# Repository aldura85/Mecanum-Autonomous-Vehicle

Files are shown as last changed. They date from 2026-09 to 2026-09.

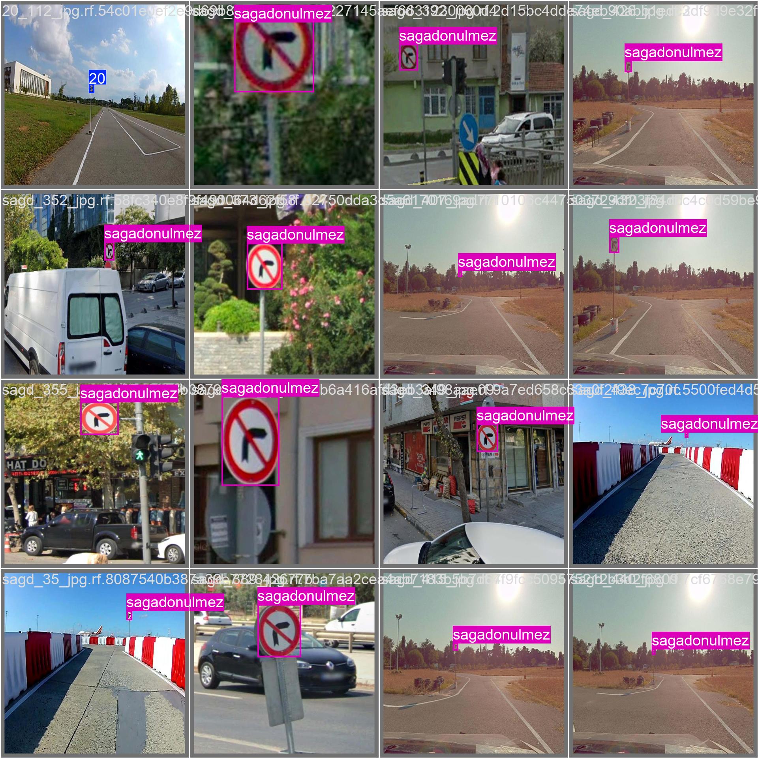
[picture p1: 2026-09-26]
project_codes/python_pc_folder/Yolo_training_reslut/val_batch0_labels.jpg

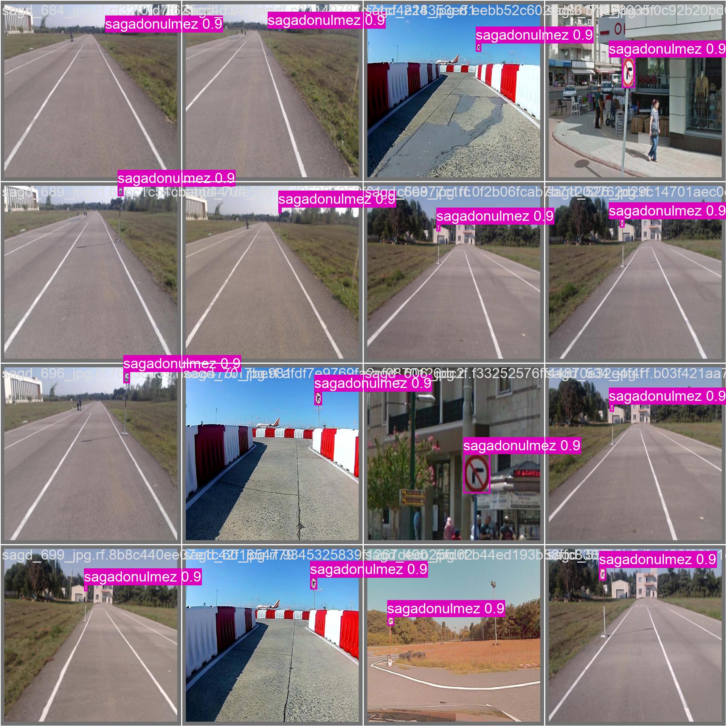
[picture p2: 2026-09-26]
project_codes/python_pc_folder/Yolo_training_reslut/val_batch2_pred.jpg

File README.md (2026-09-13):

# Mecanum Otonom Araç Platformu

Bu proje, Elektrik-Elektronik Mühendisliği bitirme projesi kapsamında geliştirilen, bilgisayarlı görü destekli otonom bir Mecanum tekerlekli araç platformudur.

Sistem; gerçek zamanlı motor ve sensör kontrolü için **STM32F407 Discovery**, görüntü işleme ve otonom navigasyon işlemleri için ise **Raspberry Pi 5** kullanmaktadır.

## Projenin Özellikleri

- Mecanum tekerlekler ile holonomik hareket
- Otonom şerit takibi
- Trafik işareti algılama ve sınıflandırma
- YOLO tabanlı görüntü işleme
- Dijkstra algoritması ile rota planlama
- Kavşaklarda otonom karar verme
- Engel algılama
- MPU6050 ile yönelim ve yaw kontrolü
- STM32 ve Raspberry Pi arasında UART haberleşmesi
- NRF24L01+ ile kablosuz manuel kontrol

## Kullanılan Teknolojiler

- STM32F407 Discovery
- Raspberry Pi 5
- C / STM32 HAL
- Python
- OpenCV
- YOLO
- Dijkstra Algoritması
- MPU6050
- Ultrasonik Sensörler
- NRF24L01+

## Sistem Yapısı

**STM32F407**
- Motor kontrolü
- Encoder okuma
- IMU verilerinin işlenmesi
- Yaw stabilizasyonu
- Ultrasonik sensörlerin kontrolü
- Gerçek zamanlı kontrol işlemleri

**Raspberry Pi 5**
- Kamera görüntüsünün işlenmesi
- Şerit takibi
- Trafik işareti tespiti
- Rota planlama
- Otonom sürüş kararları

## Proje Ekibi

- MohamedEldur Esmaeil 
- Ehsan Alzarrad

## Akademik Bilgi

**KTO Karatay Üniversitesi**  
Elektrik-Elektronik Mühendisliği  
Bitirme Projesi  
2025–2026

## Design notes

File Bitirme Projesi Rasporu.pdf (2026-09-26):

## KTO KARATAY ÜNİVERSİTESİ

## MÜHENDİSLİK VE DOĞA BİLİMLERİ FAKÜLTESİ

## ELEKTRİK ELEKTRONİK MÜHENDİSLİĞİ BÖLÜMÜ

## BİTİRME PROJESİ RAPORU

08/06/2026

Adı ve Soyadı | : Ehsan ALZARRAD & Mohammedeldur ESMAEIL HAMID
Öğrenci Numarası | : 211451020 / 221451043
Çalışma Alanı | : Otonom Araçlar, Gömülü Sistemler, Bilgisayarlı Görü
Proje Adı | : Bilgisayarlı Görü Destekli Mecanum Tekerlekli Otonom Araç Platformu
Danışman | : Dr. Öğr. Üyesi Taha Fatih ATEŞ

İÇİNDEKİLER

### 1. ÖZET

Bu çalışma, KTO Karatay Üniversitesi Elektrik-Elektronik Mühendisliği Bölümü Bitirme

Projesi | kapsamında | gerçekleştirilmiş | olup, | kapalı | alanlarda | otonom | navigasyon

gerçekleştirebilen Mecanum tekerlekli bir robot platformunun tasarımı, üretimi ve

gerçekleştirilmesini konu almaktadır. Projede düşük maliyetli donanım bileşenleri kullanılarak

şerit takibi, trafik işareti algılama, engel tespiti ve hedef noktaya otonom ulaşım görevlerini

yerine getirebilen bütünleşik bir sistem geliştirilmiştir. Çalışmanın temel amacı, LiDAR gibi

yüksek maliyetli sensörlere ihtiyaç duymadan kamera ve ultrasonik sensör tabanlı bir algılama

altyapısı ile güvenilir bir kapalı alan navigasyon sistemi oluşturmaktır.

Geliştirilen sistemde görüntü işleme ve navigasyon kararları Raspberry Pi 5 üzerinde, gerçek

zamanlı motor kontrolü ise STM32F407 mikrodenetleyicisi üzerinde gerçekleştirilmiştir. Şerit

takibi için HSV renk maskeleme, görüntü iyileştirme ve PID kontrol yöntemleri kullanılmış;

kavşak yönetimi Sonlu Durum Makinesi (FSM) yapısıyla gerçekleştirilmiştir. Hedef noktaya

ulaşım için graf tabanlı harita yapısı oluşturularak Dijkstra algoritması ile rota planlaması

yapılmıştır. Trafik işaretlerinin tespitinde YOLOv11s derin öğrenme modeli kullanılmış, engel

algılama işlemi ise kamera görüntülerinden elde edilen verilerin ultrasonik sensör ölçümleri ile

birleştirilmesiyle gerçekleştirilmiştir.

Gerçekleştirilen saha testlerinde sistemin 22–25 FPS hızında kararlı çalıştığı, trafik işareti tespit

modelinin %98,7 mAP@0.5 (Mean Average Precision) başarımına ulaştığı ve otonom

navigasyon görevlerini başarıyla tamamladığı gözlemlenmiştir. Raspberry Pi 5 ile STM32F407

arasında kurulan UART haberleşmesinde paket kaybı yaşanmamış ve sistem 3S LiPo batarya

ile yaklaşık 45 dakika kesintisiz çalışmıştır. Elde edilen sonuçlar, düşük maliyetli donanım ve

bilgisayarlı görü yöntemleri kullanılarak kapalı alan otonom navigasyonunun başarıyla

gerçekleştirilebileceğini göstermektedir.

Anahtar Kelimeler: Otonom Araç, Raspberry Pi 5, STM32F407, Bilgisayarlı Görü, Şerit

Takibi, YOLOv11s, Dijkstra Algoritması, Mecanum Tekerlek, Gömülü Sistemler.

### 2. GİRİŞ

Bu çalışma, Elektrik-Elektronik Mühendisliği Bölümü bitirme projesi dersi kapsamında

gerçekleştirilmiş olup; kapalı alan koşullarına özgü, çok yönlü hareket kabiliyetine sahip

Mecanum tekerlekli bir robot platformunun tasarımı, üretimi ve yazılımsal altyapısının

geliştirilmesini konu almaktadır. Son yıllarda robotik, yapay zeka ve gömülü sistem

alanlarındaki hızlı gelişmelerle birlikte otonom araçlar; fabrika otomasyonu, depo yönetimi,

hastane lojistiği ve akıllı bina iç mekan taşımacılığı gibi senaryolarda kritik bir öneme

kavuşmuştur. Geliştirilen platformun dar alanlarda manevra yarıçapına ihtiyaç duymadan çok

yönlü hareket edebilmesi ve LiDAR gibi yüksek maliyetli donanımlar yerine yalnızca

monoküler kamera ile ultrasonik sensör füzyonuna dayanması, projenin maliyet-etkin

mühendislik önemini ortaya koymaktadır.

Literatürde otonom araç sistemlerine yönelik var olan çalışmaların büyük çoğunluğu LiDAR,

GPS veya yüksek maliyetli sensör dizilerine dayanmaktadır [1]. Buna karşın düşük maliyetli

ve kapalı alan odaklı sistemlere yönelik bilgisayarlı görü çalışmaları görece sınırlı kalmaktadır.

Literatür incelendiğinde, çevresel ışık değişimlerinden minimum düzeyde etkilenen HSV renk

maskeleme tabanlı şerit takibi ve hata sinyalinin PID kontrolörle işlenmesi kararlı çözümler

sunmaktadır [2]. Bununla birlikte, YOLO ailesi gibi tek aşamalı nesne dedektörleriyle gerçek

zamanlı trafik işareti tespiti [3] ve topolojik haritaların çizge yapısına dönüştürülerek Dijkstra

algoritmasıyla dinamik rota planlaması yapılması [4], iç mekan navigasyonunda yeni

yaklaşımların geliştirilmesine zemin hazırlamaktadır. Bu çalışma kapsamında, Raspberry Pi 5

ve STM32 mikrodenetleyicisinin UART üzerinden dağıtık olarak haberleştiği, Sonlu Durum

Makinesi (FSM) tabanlı özgün bir otonom mimari kurgulanmıştır.

Bu raporun içeriği, sistemin tüm teknik dökümünü bütüncül bir akışla sunacak şekilde

düzenlenmiştir. Rapor kapsamında öncelikle çalışmanın amaç ve hedefleri ortaya konulmakta;

devamında platformun mekanik, elektronik ve yazılımsal bileşenlerini içeren materyal ve yöntemler açıklanmaktadır. İlerleyen kısımlarda şerit takibi, FSM durum geçişleri, Dijkstra

navigasyonu ve YOLOv11s model eğitimi gibi gerçekleştirilen tüm algoritmik çalışmalar

detaylandırılmaktadır. Yazılım ve donanım bileşenlerinin bir araya getirilmesi sürecinde

karşılaşılan entegrasyon problemleri, uygulanan mühendislik çözümleri ve deneysel saha

testlerinden elde edilen performans metrikleri ayrıntılı biçimde tartışılmaktadır. Raporun son

kısmında ise çalışmanın ortaya koyduğu ana sonuçlar, sistemin kısıtları, ileriye dönük hedefler

ve yararlanılan kaynaklar özetlenmektedir.

### 3. AMAÇ

Bu çalışmada; kapalı alan koşullarına uygun, Mecanum tekerlekli otonom bir robot

platformunun tasarımı ve gerçekleştirilmesi amaçlanmaktadır. Geliştirilen platform; şerit

takibi, trafik işareti tespiti, engel algılama ve hedef konuma otonom ulaşım işlevlerini yüksek

maliyetli sensörlere ihtiyaç duymadan, temel kamera ve ultrasonik sensör donanımlarıyla

yerine getirmektedir.

Proje kapsamında LiDAR kullanılmadan, yalnızca Pi Kamera V3 Wide ve ultrasonik sensör ile

kapalı alan koşullarına uygun bir otonom navigasyon sistemi inşa edilmektedir. Sistem; HSV

renk maskeleme ile şerit takibini, YOLOv11s tabanlı trafik işareti tespitini (dur, sağ dönüş, sol

dönüş, dönüş yasağı ve giriş yasağı işaretleri), yol içindeki yabancı nesnelerin kontur analizi

yöntemiyle kamera üzerinden tespitini ve Dijkstra algoritmasına dayalı graf tabanlı rota

planlamasını kapsamaktadır.

Sistemin mimarisi, işlemlerin eşzamanlı ve güvenilir bir şekilde yürütülmesi amacıyla dağıtık

bir yapıda tasarlanmıştır. Görüntü işleme ve navigasyon kararları Raspberry Pi 5 üzerinde

Python ile yürütülürken; gerçek zamanlı motor kontrolü STM32F407 mikrodenetleyicisinde C

dili ile PID algoritmaları aracılığıyla sağlanmaktadır. Bu yapıda kamera; şerit takibi, trafik

işareti ve engel tespiti için birincil algılama kaynağı olarak kullanılmakta, ultrasonik sensör ise

yakın mesafe engel uyarısını desteklemektedir.

Çalışmanın temel motivasyonu ve literatüre özgün katkısı; pahalı ve karmaşık sensörlere

başvurulmaksızın, düşük maliyetli ve yaygın erişilebilir donanımlarla kapalı alan otonom

navigasyonunun gerçekleşebilirliğini ortaya koymaktır. Platformda kullanılan Mecanum

tekerlek mimarisi dar kapalı alan geçitlerinde yüksek manevra kabiliyeti sağlarken, kurulan

dağıtık denetim mimarisi sayesinde gerçek zamanlı motor kontrolü ile bilgisayarlı görü

işlemlerinin birbirinden bağımsız ve stabil biçimde çalışmasına olanak tanınmıştır.

### 4. HEDEFLER

Çalışmanın ana amacına ulaşması sürecinde tamamlanması gereken ölçülebilir yan hedefler

belirlenmiştir. Bu kapsamda ilk temel hedef, aracın kapalı alan zeminindeki şerit çizgilerini

HSV renk maskeleme yöntemiyle algılayarak yol merkezini maksimum ±30 piksel hata payı

içinde otonom olarak takip edebilmesi ve her dönüş manevrası sonrasında yanal kaymasını

düzelterek kendisini yeniden merkezlenebilmesidir. Sistemde gerçek zamanlı çalışabilirlik

kriterini güvence altına almak adına, görüntü işleme döngüsünün saniyede en az 20 kare (20

FPS) hızında kesintisiz olarak yürütülmesi hedeflenmektedir.

Otonom navigasyon ve rota planlama süreçleri açısından en temel beklenti, aracın belirlenen

bir başlangıç noktasından hedef noktaya tam otonom ve güvenli bir şekilde ulaşabilmesidir. Bu

doğrultuda sistemin, Dijkstra algoritması vasıtasıyla graf yapısı üzerinde en kısa yolu optimum

şekilde hesaplayabilmesi, tek şerit, çift şerit ve kavşak durumlarını ayırt edebilmesi ve olası

çıkmaz sokak veya engel durumlarında alternatif rotaları dinamik olarak üretebilmesi

amaçlanmaktadır. Algılama işlevleriyle entegre olarak, YOLOv11s modelinin dur, sağa dönüş,

sola dönüş, dönüş yasağı ve giriş yasağı işaretlerini en az %85 mAP50 doğruluğuyla

sınıflandırabilmesi ve tespit edilen kurala göre araç davranışının anlık olarak güncellenebilmesi

hedeflenmektedir.

Tüm bu otonom sürüş ve navigasyon yeteneklerine ek olarak, yol bölgesi içindeki yabancı

nesnelerin kontur analizi yöntemiyle kamera üzerinden tespit edilmesi planlanmaktadır. Elde

edilen bu görsel verinin, ön ultrasonik sensörden sağlanan mesafe bilgisiyle desteklenerek

kararlı ve güvenilir bir çarpışma önleme mekanizmasının kurulması hedeflenmektedir. Son

olarak, tüm bu yazılımsal ve donanımsal mimarinin sürdürülebilirliği kapsamında; aracın 3S

LiPo pil ile en az 30 dakika kesintisiz çalışabilmesi sistem entegrasyonunun temel performans

gereksinimi olarak belirlenmiştir.

### 5. MATERYAL & METOT

Proje kapsamında belirlenen hedeflere ulaşabilmek için donanım ve yazılım bileşenleri

bütüncül bir yaklaşımla tasarlanmış; veri toplama, işleme ve karar üretme süreçleri dağıtık bir

mimari üzerinde gerçekleştirilmiştir. Çalışmanın temel araştırma yöntemi, kapalı alan otonom

navigasyon probleminin çözümü için görsel ve konumsal verilerin toplanarak gerçek zamanlı

analiz edilmesine dayanmaktadır. Sistem genelinde çevresel veri toplama işlemi, algılama

katmanını oluşturan Pi Kamera V3 Wide ve aracın ön cephesine konumlandırılmış tek bir AJ-

SR04M ultrasonik sensör aracılığıyla sağlanmaktadır. Toplanan bu ham veriler, işleme katmanı

olan Raspberry Pi 5 mikrobilgisayarına aktarılarak proje araştırmacıları tarafından geliştirilen algoritmalarla analiz edilmekte ve otonom karar süreçlerinde yorumlanmaktadır. Üretilen

navigasyon kararları ise tahrik katmanını yöneten STM32F407 mikrodenetleyicisine iletilerek

sistemin fiziksel eylemlerine dönüştürülmektedir. Tüm bu karmaşık veri akışı ve kontrol

döngüsünün nasıl kurgulandığı, çalışmanın şeffaflığını ve mühendislik açısından tekrar

edilebilirliğini sağlamak amacıyla spesifik aşamalara bölünmüştür. Bu bağlamda projenin

metodolojisi sırasıyla; robot platformunun fiziksel inşasını açıklayan mekanik tasarım ve

üretim, sistemin yapıtaşlarını oluşturan donanım bileşenleri, veri ile güç akışını tanımlayan

sistem mimarisi ve dağıtık kontrol algoritmalarını işleyen yazılım mimarisi alt başlıkları

çerçevesinde detaylandırılmıştır.

### 5.1 Mekanik Tasarım ve Üretim

Aracın mekanik platformu, araştırma kapsamında proje gereksinimlerine uygun olarak özel

olarak tasarlanmış ve üretilmiştir. Şasi ve gövde mimarisinin bilgisayar destekli tasarım (CAD)

süreçleri Autodesk Fusion 360 yazılımı ortamında gerçekleştirilmiştir. Şekil 1a'da sistemin

donanım bileşenlerinin yerleşimi ve şasi üzerindeki katmanlı mimarisi görülmektedir. Motor-

tekerlek bağlantı aparatları dahil olmak üzere sisteme özgü tüm mekanik bileşenler 3D baskı

teknolojisiyle imal edilmiştir. Sistemde hazır yapısal donanım olarak yalnızca 80 mm çapındaki

Mecanum tekerlek seti kullanılmış, bunun dışındaki tüm taşıyıcı mimari araştırmacılar

tarafından sıfırdan geliştirilmiştir. Şekil 1b'de şasinin izometrik CAD modeli ve bu modele

entegre edilen 3D baskılı motor-tekerlek bağlantı aparatları verilmiştir. Platformun tahrik

sistemi, her bir tekerleğe bağımsız olarak güç aktaran dört adet 12V gerilimli, 37mm çaplı ve

600 RPM devirli redüktörlü DC motordan oluşmaktadır. Otonom hareket kabiliyeti açısından

kritik bir detay olarak Mecanum tekerlekler, literatürde yaygın olarak tercih edilen standart

çapraz konfigürasyonu şeklinde monte edilmiştir.

Bu asimetrik yerleşim modeli Mecanum ters kinematik hesaplamalarına doğrudan entegre

edilerek yazılım katmanında gerekli matematiksel uyarlamalar sağlanmıştır.

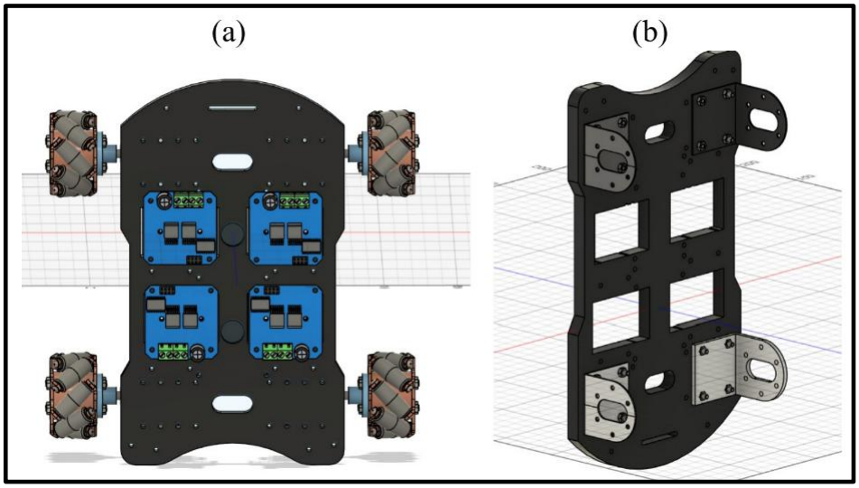
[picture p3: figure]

Şekil 1. Aracın mekanik şasi CAD modellemeleri: (a) Donanım yerleşimini gösteren üstten

görünüm, (b) 3D baskılı motor bağlantı aparatlarını içeren izometrik görünüm

Sensör ve donanım bileşenlerinin şasi üzerindeki fiziksel yerleşimi, ağırlık merkezini optimize

etmek ve sinyal/güç hatları arasındaki elektromanyetik etkileşimi en aza indirmek amacıyla

katmanlı bir mimaride planlanmıştır. Bu doğrultuda, alt katmanda güç yönetimini ve tahrik

sinyallerini üstlenen STM32F407 mikrodenetleyicisi, motor sürücüler ve güç dağıtım birimleri

konumlandırılırken; üst katmana aktif soğutma sağlayan fanlı alüminyum muhafaza

içerisindeki Raspberry Pi 5 entegre edilmiştir. Çevresel algılamanın birincil kaynağı olan Pi

Kamera V3 Wide ise, şerit çizgilerini ve nesneleri maksimum görüş alanıyla tarayabilmesi

adına aracın ön cephesine, yol yüzeyini optimum iz düşümüyle görecek geometrik bir eğimle

sabitlenmiştir.

### 5.2 Donanım Bileşenleri

Sistemin üst düzey işlem ve karar alma birimi olarak Raspberry Pi 5 (8 GB) mikrobilgisayarı

kullanılmaktadır. 2,4 GHz saat hızında çalışan dört çekirdekli ARM Cortex-A76 işlemcisi ve 8

GB LPDDR4X belleğiyle donatılmış olan bu donanım; görüntü işleme, navigasyon karar alma,

trafik işareti tespiti ve web arayüzü sunucu görevlerini eşzamanlı olarak yürütmektedir. Yoğun

işlem yükü altında termal performansın korunabilmesi amacıyla Raspberry Pi 5, aktif soğutma

sağlayan fanlı alüminyum muhafaza kutusu içerisine entegre edilmiştir. Sistemin alt düzey ve

gerçek zamanlı motor kontrol süreçleri ise STM32F407G-DISC1 geliştirme kartı tarafından

üstlenilmektedir.

168 MHz hızında çalışan Cortex-M4 çekirdeğine sahip olan bu mikrodenetleyici, döngü süresi

açısından yüksek hassasiyet gerektiren PID hesaplamalarını ve dört kanallı PWM üretimini

etkin biçimde gerçekleştirmektedir. Kontrol mimarisinde STM32, Raspberry Pi'den UART

protokolü üzerinden aldığı doğrusal ve açısal hız komutlarını Mecanum ters kinematik

modeliyle bireysel tekerlek hızlarına dönüştürmekte ve her bir tekerlek için bağımsız PID

döngüleri çalıştırmaktadır. Şekil 2'de sistemin temel işlem ve kontrol birimlerini oluşturan

donanımlar verilmiştir.

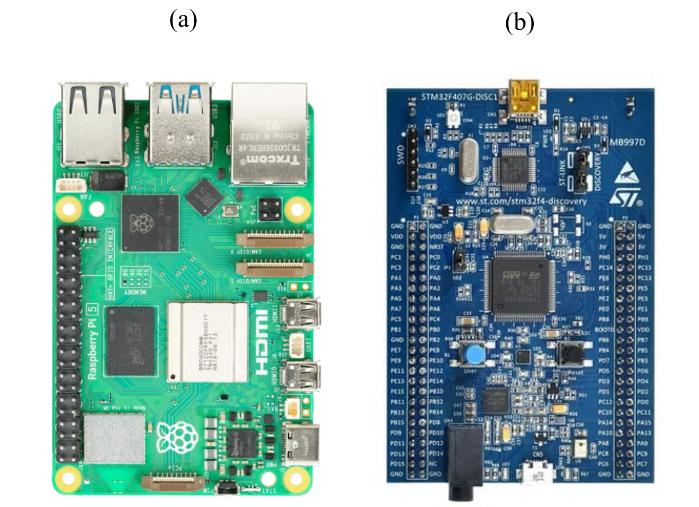
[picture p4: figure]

Şekil 2. Sistemin işlemci ve denetleyici birimleri: (a) Raspberry Pi 5 mikrobilgisayarı [5],

(b) STM32F407G-DISC1 geliştirme kartı [6]

Otonom navigasyonun temel verisi olan görsel akış, IMX708 sensörlü ve 120 derece yatay

görüş açısına sahip Pi Kamera V3 Wide ile elde edilmektedir; bu geniş perspektif, aracın kapalı

alan yol sınırlarını erken ve kapsayıcı bir biçimde algılamasına olanak tanımaktadır. Çevresel

algılamayı desteklemek amacıyla aracın ön kısmına konumlandırılmış olan AJ-SR04M

ultrasonik sensörden gelen mesafe verisi de UART modunda doğrudan mikrodenetleyici

üzerinden okunmaktadır. Şekil 3'te aracın çevresel algılama görevlerini yürüten sensör

donanımları gösterilmiştir.

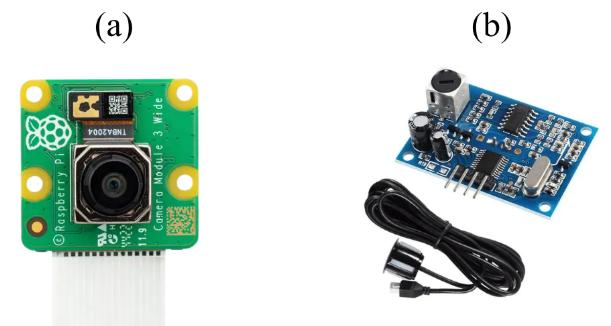
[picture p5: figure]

Şekil 3. Algılama donanımları: (a) Pi Kamera V3 Wide modülü [7], (b) AJ-SR04M

ultrasonik sensör [8]

Hareket kabiliyetinin fiziksel olarak sağlanması için her bir tekerleğin tahrik devresi, 40 A akım

kapasitesine sahip BTS7960B H-köprüsü motor sürücü modülleriyle sürülmektedir. Tüm bu

elektronik altyapının güç yönetimi, verimlilik ve güvenlik esaslarına göre iki ayrı hattan

sağlanmaktadır. PDB-XT60 güç dağıtım kartı, 3S LiPo bataryadan aldığı enerjiyi yüksek akım

çeken motor sürücülere ve genel güç hatlarına doğrudan iletirken; XL4016 entegreli XH-M403

düşürücü regülatör, batarya gerilimini Raspberry Pi 5'in güvenli çalışma sınırları olan 5,1 V

seviyesine regüle etmektedir. Sistemin otonom ve manuel çalışma modları arasındaki geçiş

yönetimi ise NRF24L01 radyo frekans modülü aracılığıyla kurulan RC kumanda bağlantısıyla

sağlanmakta olup, operatörün kumanda üzerindeki sol joystick tuşuna basmasıyla araç

donanımsal olarak tam otonom sürüş moduna geçiş yapmaktadır. Şekil 4'te sistemin tahrik, güç

yönetimi ve haberleşme bileşenleri sunulmuştur. Tablo 1'de ise sistem mimarisinde kullanılan

tüm donanım bileşenleri ve teknik özellikleri detaylı olarak listelenmiştir.

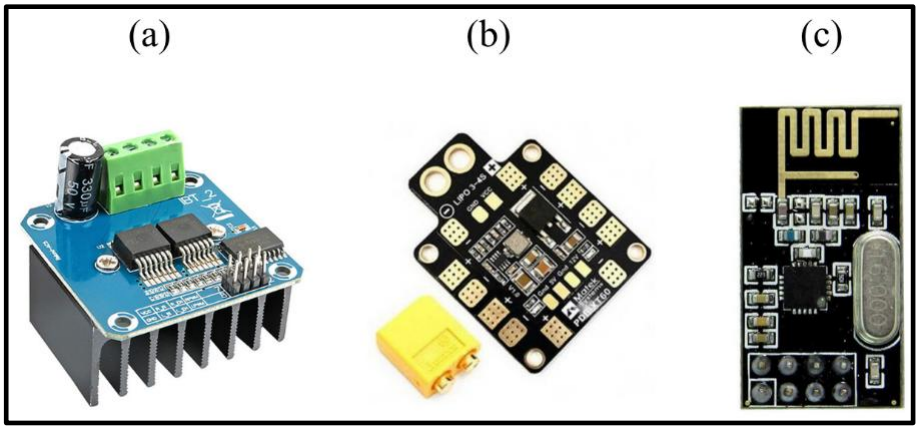
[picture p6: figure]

Şekil 4. Tahrik, güç ve haberleşme bileşenleri: (a) Motor sürücü [9], (b) Güç dağıtım ve

regülasyon modülleri [10], (c) NRF haberleşme modülü [11]

Tablo 1. Sistem mimarisinde kullanılan donanım bileşenleri ve teknik özellikleri

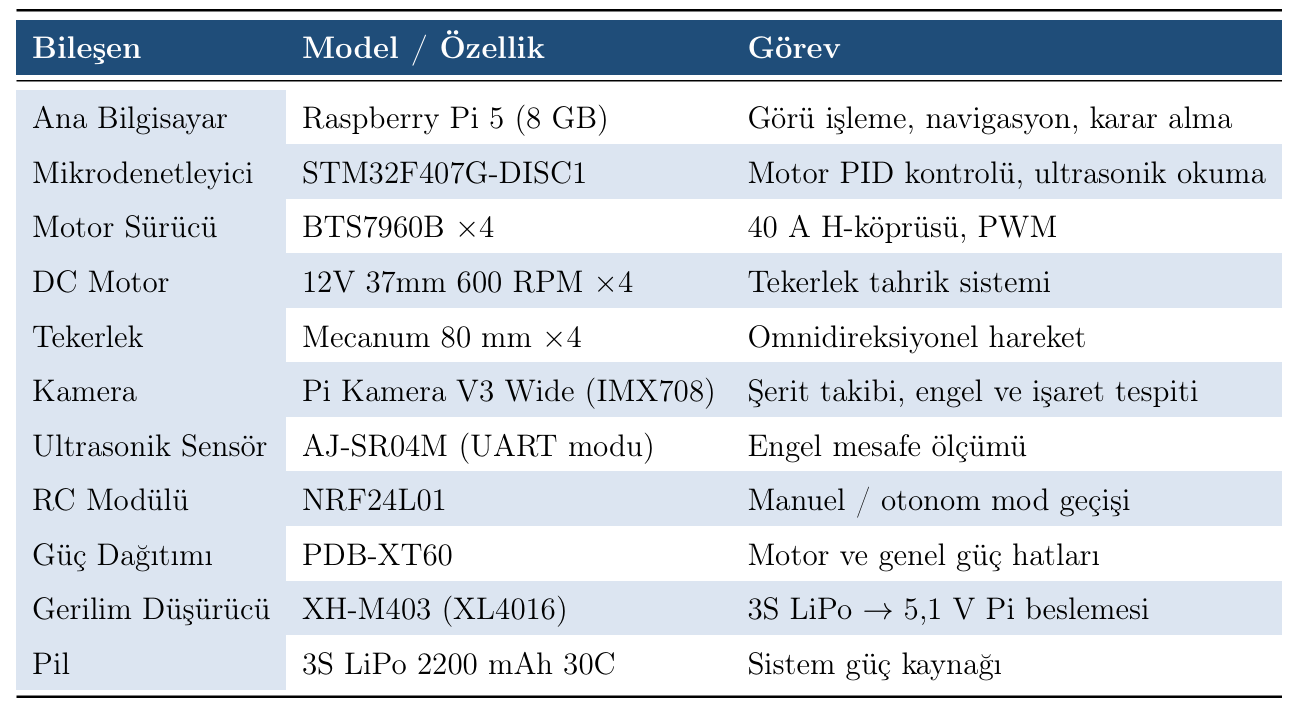
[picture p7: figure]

### 5.3 Sistem Mimarisi

Geliştirilen otonom robot platformu; algılama, işleme ve tahrik olmak üzere üç ana katmandan

oluşan dağıtık bir denetim mimarisi üzerine inşa edilmiştir. Bu mimari tercih, gerçek zamanlı

motor kontrolü ile hesaplama yoğun görüntü işleme görevlerinin birbirinden bağımsız ve kararlı

biçimde yürütülmesini sağlamaktadır. Algılama katmanında Pi Kamera V3 Wide ve AJ-SR04M

ultrasonik sensör yer almaktadır. Kamera görüntüsü doğrudan Raspberry Pi 5'e aktarılırken,

ultrasonik sensörden gelen mesafe verisi STM32F407 mikrodenetleyicisi üzerinden okunmaktadır. İşleme katmanında Raspberry Pi 5; şerit takibi, engel tespiti ve Dijkstra tabanlı

rota planlama gibi üst düzey navigasyon görevlerini yürütmektedir. Tahrik katmanında ise

STM32F407 mikrodenetleyicisi, üst denetleyiciden aldığı doğrusal (vx, vy) ve açısal (wz) hız

komutlarını mecanum ters kinematik modeliyle dört tekerleğin bireysel hız referanslarına

dönüştürmekte ve her bir tekerlek için bağımsız PID kontrol döngüleri çalıştırmaktadır. Şekil

5'te sistemi oluşturan katmanları ve haberleşme arayüzlerini gösteren detaylı sistem blok

diyagramı verilmiştir.

Sistem içerisindeki donanımlar arası veri akışı ve haberleşme, farklı protokoller üzerinden senkronize bir biçimde gerçekleştirilmektedir. İki işlemci (Raspberry Pi 5 ve STM32F407)

arasındaki temel haberleşme, 115200 baud hızında UART seri iletişim protokolü üzerinden

sağlanmaktadır.

Güvenilir bir veri aktarımı için Raspberry Pi 5, her kontrol döngüsünde STM32'ye sabit

uzunluklu bir veri çerçevesi (paket) göndermekte; bu çerçeve 0xAA55 başlık baytı (header),

hız komutları ve veri bütünlüğünü doğrulamak amacıyla 8-bit toplamsal sağlama (checksum)

değerinden oluşmaktadır.

Öte yandan, mikrobilgisayarın hesaplama yükünü dengelemek ve donanım kaynaklarını verimli

kullanmak amacıyla trafik işareti tespiti görevi, yerel ağ üzerinden harici bir kişisel bilgisayar

(PC) üzerinde koşan YOLOv11s modeline devredilmiştir. Bu bağlamda Raspberry Pi, aldığı

anlık kamera akışını TCP soketi üzerinden PC'ye aktarmakta ve PC üzerinde gerçekleştirilen

nesne tespiti sonuçları tekrar Pi'ye geri döndürülerek navigasyon algoritmasına entegre

edilmektedir. Sistemin tüm bu anlık çalışma durumu, sensör verileri ve karar mekanizmaları ise

Raspberry Pi 5 üzerinde barındırılan HTTP tabanlı bir web arayüzü (dashboard) üzerinden

eşzamanlı olarak izlenebilmektedir.

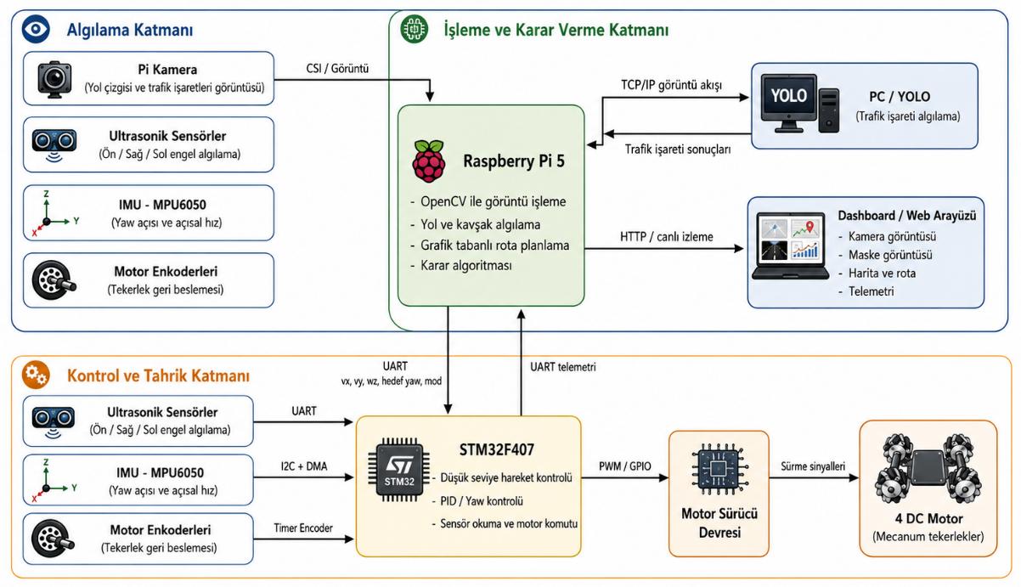
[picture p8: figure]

Şekil 5. Sistemin algılama, işleme ve tahrik katmanları ile donanımlar arası haberleşme

arayüzlerini gösteren blok diyagram

### 5.4 Yazılım Mimarisi

Sistemin yazılım katmanı; Raspberry Pi 5 mikrobilgisayarı üzerinde koşan Python tabanlı

algoritmalar, STM32F407 mikrodenetleyicisi üzerinde çalışan donanım soyutlama katmanı

(HAL) destekli C gömülü yazılımı ve yerel ağdaki bir kişisel bilgisayar (PC) üzerinde görev

yapan YOLO çıkarım sunucusu olmak üzere üç ayrı platform üzerinde geliştirilmiştir. Şekil

6'da bu üç platform arasındaki yazılım modüllerini ve veri akışını gösteren mimari diyagram sunulmuştur. Üst düzey karar mekanizmasını oluşturan Raspberry Pi 5 tarafındaki yazılım

mimarisi; görüntü yakalama, şerit ve engel tespiti, navigasyon karar alma, motor komut üretimi,

YOLO akış istemcisi ve web arayüzü (dashboard) sunucusu gibi alt modüllerden inşa edilmiştir.

Görsel veri yakalama süreçleri "picamera2" kütüphanesi aracılığıyla gerçekleştirilmekte; elde

edilen ham görüntü matrisleri OpenCV kütüphanesi kullanılarak işlenip şerit çizgileri ve

çevresel engeller tespit edilmektedir. Otonom sürüşe yönelik navigasyon kararları, Dijkstra

algoritmasına dayanan graf tabanlı bir rota planlayıcısı tarafından anlık olarak üretilmekte ve

hesaplanan komut vektörleri UART protokolü üzerinden STM32'ye iletilmektedir. Tüm bu

karar süreçlerinin, sensör verilerinin ve sistem durumunun dışarıdan izlenebilmesi amacıyla

standart Python HTTP sunucusu tabanında çalışan bir web arayüz modülü eşzamanlı olarak

yürütülmektedir.

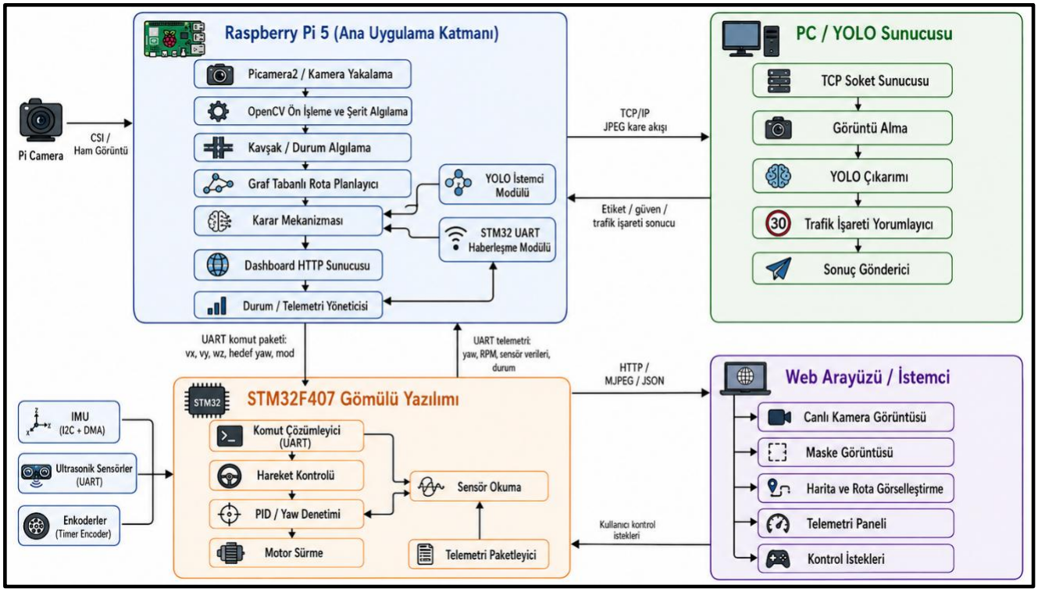
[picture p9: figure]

Şekil 6. Sistemin dağıtık yazılım mimarisini, çalışan modülleri ve platformlar arası veri

akışını gösteren blok diyagramı

Alt düzey tahrik ve kontrol süreçlerini yöneten STM32F407 tarafındaki gömülü yazılım, C

programlama dili ve STMicroelectronics HAL (Hardware Abstraction Layer) kütüphaneleri

kullanılarak geliştirilmiştir. Bu yazılım katmanı; Raspberry Pi'den gelen UART veri

çerçevelerinin ayrıştırılması, doğrusal ve açısal hız referanslarının Mecanum ters kinematik

denklemleriyle tekerlek hızlarına dönüştürülmesi, bu hızları korumak üzere dört bağımsız PID

kontrol döngüsünün işletilmesi ve motor sürücülere uygun PWM sinyallerinin üretilmesi

görevlerini gerçek zamanlı olarak yürütmektedir. Aynı döngü içerisinde ultrasonik sensörden

gelen mesafe verilerinin okunması ve NRF24L01 modülü üzerinden alınan radyo frekanslı RC

kumanda sinyallerinin işlenerek otonom/manuel mod geçişlerinin sağlanması da bu işlemci

tarafından yönetilmektedir. Yazılım mimarisini tamamlayan PC tarafındaki harici sunucu

süreci ise, TCP soket bağlantısı üzerinden Pi'den gelen anlık görüntü karelerini teslim almakta,

eğitilmiş YOLOv11s yapay sinir ağı modeli üzerinden trafik işareti sınıflandırmasını

gerçekleştirmekte ve elde edilen çıkarım sonuçlarını ağ üzerinden gecikmesiz olarak

navigasyon katmanına geri iletmektedir.

### 6. YAPILAN ÇALIŞMALAR

Bu bölümde, önceki kısımlarda kavramsal tasarımı ve metodolojik altyapısı sunulan otonom

robot platformunun fiziksel üretim, donanım entegrasyonu, yazılım geliştirme ve sistem test

süreçleri detaylandırılmaktadır. Teorik olarak kurgulanan dağıtık kontrol mimarisi, otonom

navigasyon algoritmaları ve donanım bileşenleri; proje takvimi doğrultusunda aşama aşama gerçeklenmiş ve entegre edilmiştir. İlerleyen alt başlıklarda sırasıyla; şasi mekaniğinin fiziksel

olarak imal edilip montajlanması, elektronik güç ve veri hatlarının çekilmesi, şerit takibi ve

yapay zeka modellerinin eğitilerek donanıma gömülmesi süreçleri anlatılmaktadır. Bölümün

son kısmında ise sistemin otonom ve manuel sürüş modlarındaki performansına yönelik

gerçekleştirilen laboratuvar testleri ve elde edilen deneysel veriler sunulmaktadır.

### 6.1 Mekanik Platform Üretimi ve Fiziksel Montaj

Projenin | mekanik altyapısı, | önceki bölümlerde | mimarisi detaylandırılan | tasarım

parametrelerine sadık kalınarak fiziksel üretime geçirilmiştir. Autodesk Fusion 360 ortamında

oluşturulan bilgisayar destekli tasarım (CAD) modelleri, fiziksel imalata hazırlık aşamasında

dilimleme (slicing) yazılımlarına aktarılmış ve robotun maruz kalacağı fiziksel stresler göz

önünde bulundurularak optimum mekanik dayanımı sağlayacak yüksek bir iç doluluk oranında parametrelendirilmiştir. Üretim materyali olarak, kapalı alan test koşullarında motor torklarına

karşı yeterli mukavemeti ve titreşim sönümlemeyi sağlayan PLA (Polilaktik Asit) filament

tercih edilerek FDM (Eriyik Yığma Modelleme) teknolojisiyle 3D baskı işlemleri

gerçekleştirilmiştir. Şekil 8'de şasi parçalarının 3D baskı süreci ve imalattan çıkan prototip mekanik bileşenler verilmiştir. Üretimi tamamlanan taşıyıcı parçaların yüzey temizliği ve

tolerans ayarlamaları yapıldıktan sonra fiziksel montaj ve kalibrasyon aşamasına geçilmiştir.

Dört adet redüktörlü DC motor, 3D baskılı özel bağlantı aparatları aracılığıyla ana şasiye

vidalanarak sabitlenmiş ve Mecanum tekerlekler planlanan asimetrik düzende şaftlara sıkı

geçme ile entegre edilmiştir. Montajın son aşamasında, elektronik kartların ve 3S LiPo

bataryanın yerleşimi için planlanan katmanlı yapı fiziksel olarak kurulmuş; aracın ağırlık

merkezinin dört tekerleğe homojen olarak dağıldığı mekanik testlerle doğrulanmıştır. Şekil 7'de

tüm donanımların şasi üzerine entegre edildiği ve testlere hazır hale getirilen fiziksel araç

platformu gösterilmiştir.

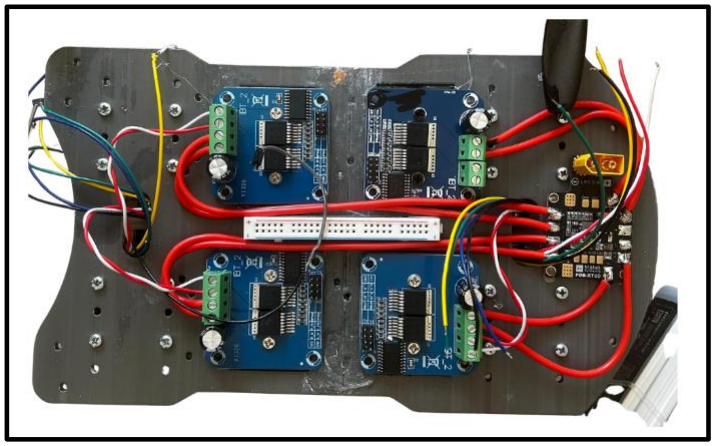
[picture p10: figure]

Şekil 7. Montajı tamamlanmış ve donanım entegrasyonu sağlanmış fiziksel robot platformu

### 6.2 Donanım Entegrasyonu ve Devre Tasarımı

Mekanik platformun tamamlanmasının ardından elektronik bileşenlerin fiziksel entegrasyonu

ve güç-sinyal devrelerinin oluşturulması aşamasına geçilmiştir. Bu süreçte her bileşenin

beslenme gereksinimleri, haberleşme arayüzleri ve mekanik montaj noktaları ayrı ayrı

değerlendirilerek sistematik bir entegrasyon planı izlenmiştir. Güç dağıtımı PDB-XT60 kartı

üzerinden gerçekleştirilmektedir. 3S LiPo batarya bu karta bağlanmakta; kart üzerinden yüksek

akım çeken motor sürücülere doğrudan güç sağlanmaktadır.

Raspberry Pi 5 mikrobilgisayarının beslenmesi ise XH-M403 düşürücü regülatör (buck

converter) aracılığıyla ayrı bir hattan 5,1 V ve 5 A kapasiteyle temin edilmektedir. Geliştirme

ve yazılım aşamasında sistem güvenliği için Pi 5 orijinal adaptörü kullanılmış, saha testlerine

geçişte ise regülatör devresi aktif edilmiştir (Şekil 8). Testler sırasında regülatör çıkışındaki

trimpotun (potansiyometre) araç titreşimiyle kayarak çıkış gerilimini değiştirme riski tespit

edilmiş ve bu bileşen hızlı yapıştırıcı ile sabitlenerek donanımsal güvenlik sağlanmıştır. Güç

hattının yüksek akım gereksinimini stabil bir şekilde karşılamak amacıyla 6 A akım taşıma

kapasitesine sahip nitelikli bir şarj kablosu tercih edilmiştir.

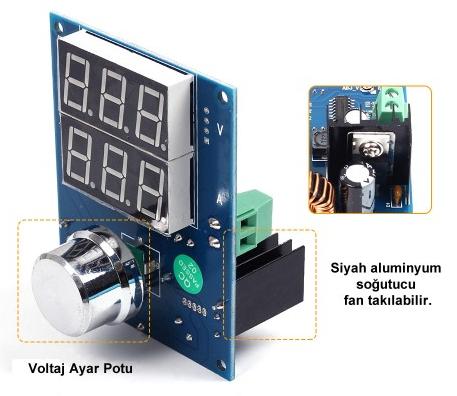
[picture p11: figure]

Şekil 8. XH-M403 XL4016 Ayarlanabilir Güç Kaynağı [12]

Sistemin alt düzey denetleyicisi olan STM32F407G-DISC1 geliştirme kartı da regülatör

üzerinden sağlanan 5 V hattı ile beslenmektedir. Sinyal entegrasyonu kapsamında, her bir

tekerleğe ait BTS7960B motor sürücü modülleri STM32'nin PWM çıkış pinlerine bağlanmıştır. Üst ve alt denetleyiciler (STM32 ile Raspberry Pi 5) arasındaki ana veri köprüsü, /dev/serial0

portu üzerinden 115200 baud hızında çalışan UART protokolü ile fiziksel olarak kurulmuştur.

Çevresel algılama birimlerinden AJ-SR04M ultrasonik sensör, standart darbe/yankı modundan

çıkarılarak üzerine R19 direnci (47kΩ) lehimlenmiş ve doğrudan STM32'nin UART

donanımına entegre edilmiştir.

NRF24L01 radyo frekans modülü STM32'nin SPI arayüzüne, Pi Kamera V3 Wide modülü ise

CSI şerit kablosuyla doğrudan Raspberry Pi 5 portuna bağlanmıştır. Fiziksel montaj sürecinde

yaşanan en kritik donanım arızası; izolasyon eksikliği nedeniyle regülatör pinlerinin STM32'nin

GND hattına temas etmesi sonucu oluşan kısa devre ve mikrodenetleyici kartının yanmasıdır.

Arızalanan kart yenisiyle değiştirilmiş, tüm kablo bağlantıları izole edilmiş ve bileşenlerin şasi

üzerindeki fiziksel yerleşimleri kısa devre riskini ortadan kaldıracak şekilde yeniden

düzenlenmiştir. Tablo 2'de donanım entegrasyonu sürecinde karşılaşılan temel sorunlar ve

uygulanan mühendislik çözümleri özetlenmiştir.

Tablo 2. Donanım entegrasyonu sürecinde karşılaşılan sorunlar ve uygulanan çözümler

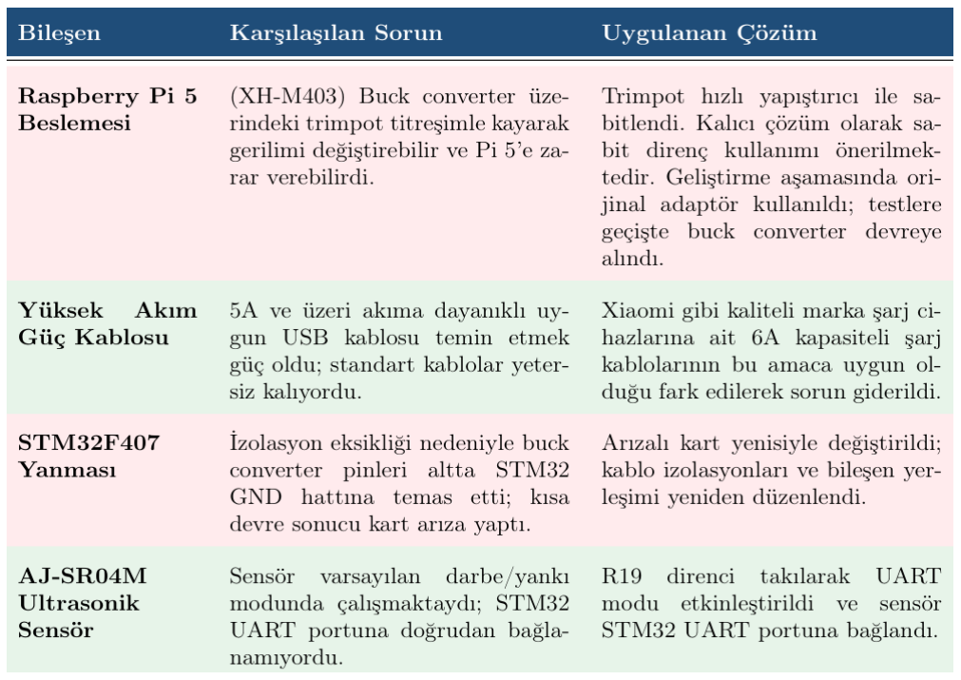
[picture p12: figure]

### 6.3 Raspberry Pi 5 Yazılım Ortamı ve Geliştirme Süreci

Otonom platformun yazılım geliştirme süreçleri, projenin evrimsel gelişimine paralel olarak iki

farklı fazda yürütülmüştür. Projenin ilk aşamasında LiDAR tabanlı bir navigasyon altyapısı

hedeflenmiş; bu doğrultuda Raspberry Pi 5 üzerinde Ubuntu Server tabanlı ROS (Robot

Operating System) ekosistemi kurulmuştur. Ancak geliştirme sürecinde, aracın kapalı alan

otonom görevleri için kamera ağırlıklı bir algılama mimarisinin daha yüksek başarım sağladığı

gözlemlenmiş ve ROS ekosisteminin yarattığı karmaşıklık katmanının, gerçek zamanlı görüntü

işleme performansını kısıtladığı tespit edilmiştir. Bu teknik değerlendirme sonucunda, sistem

daha yalın ve yüksek performanslı bir yapıya kavuşturulması amacıyla ROS kullanımından

vazgeçilmiş; işletim sistemi olarak Debian tabanlı, 64-bit mimariye sahip Raspberry Pi OS (masaüstü sürümü) tercih edilmiştir. İşletim sistemi imajı, Raspberry Pi Imager yazılımı

kullanılarak yüksek hızlı microSD kartlara yazılmış; bu aşamada sistemin saat dilimi, ağ

ayarları ve SSH erişim yapılandırmaları imaj yazma sürecinde önden tanımlanarak "tak-çalıştır"

bir kurulum elde edilmiştir.

Masaüstü sürümünün seçilmesindeki temel motivasyon; görüntü işleme algoritmalarının

geliştirilmesi sırasında OpenCV görselleştirme pencerelerinin, hata ayıklama (debug)

arayüzlerinin ve diğer grafiksel geliştirme araçlarının düşük gecikmeyle kullanılabilmesidir. Bu

ortamda; görüntü yakalama için picamera2, nesne tespiti ve sınıflandırma için ultralytics

(YOLO), seri haberleşme için pyserial ve temel matris işlemleri için OpenCV kütüphaneleri optimize edilerek entegre edilmiştir. Yazılım geliştirme ve donanım doğrulama süreçleri,

"headless" (monitörsüz) çalışma prensibiyle yürütülmüştür. Sisteme terminal erişimi SSH

protokolüyle sağlanırken, grafiksel arayüzlere ve masaüstü hata ayıklama ekranlarına VNC

(Virtual Network Computing) protokolü üzerinden uzaktan erişim gerçekleştirilmiştir. Şekil

9’da geliştirme bilgisayarı üzerinden VNC ile Raspberry Pi 5 masaüstüne erişim sağlanan;

sistem arayüzünün ve uzak masaüstü bağlantısının aktif olduğu çalışma ortamı görülmektedir.

Dosya transferleri ve kaynak kod güncellemeleri ise Windows tabanlı geliştirme bilgisayarı

üzerinden SCP (Secure Copy) protokolüyle hızlı ve güvenli bir şekilde yönetilmiştir.

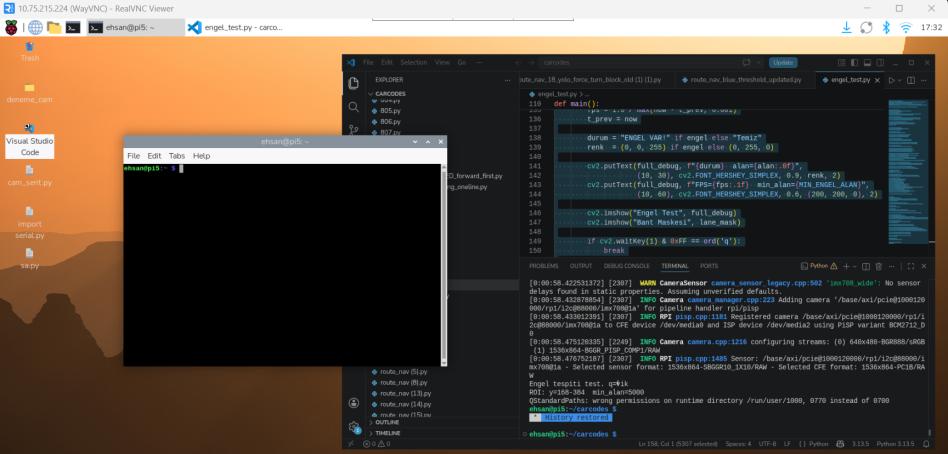
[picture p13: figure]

Şekil 9. VNC protokolü ile Raspberry Pi 5 masaüstüne uzaktan erişim ve sistem arayüzü

görünümü.

### 6.4 Şerit Takip Algoritması

Şerit takip algoritması, kapalı alan zemininde renkli bantlarla işaretlenmiş yol sınırlarını gerçek

zamanlı olarak tespit etmek ve aracın yol merkezinde kararlı bir şekilde seyretmesini sağlamak

amacıyla geliştirilmiştir. Sistem; görüntü iyileştirme, renk maskeleme, üç bantlı bölge analizi

ve PID (Proportional-Integral-Derivative) tabanlı hız kontrolü aşamalarından oluşan modüler

bir işlem hattı (pipeline) yapısına sahiptir (Şekil 10).

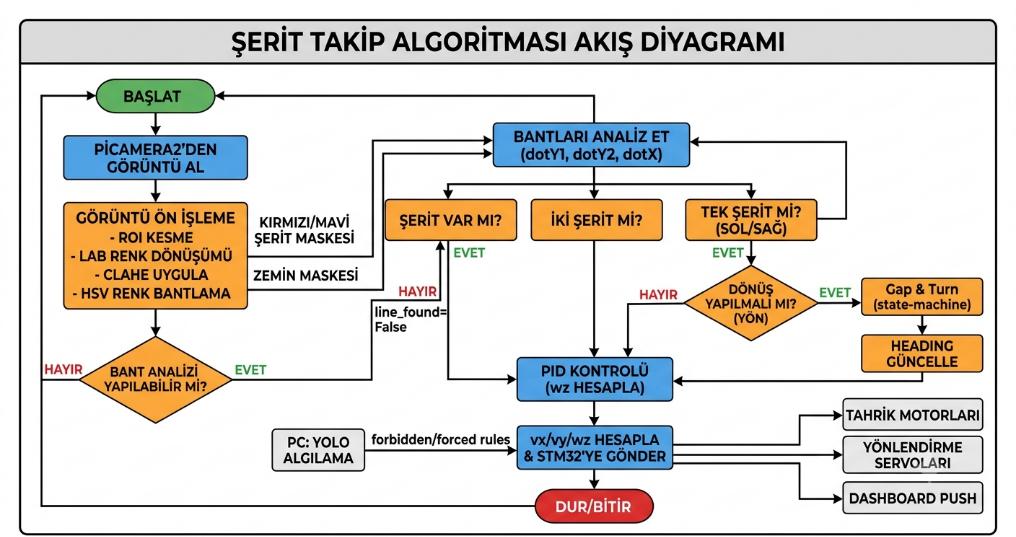
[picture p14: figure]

Şekil 10. Şerit takip algoritması akış diyagramı.

### 6.4.1 Görüntü Ön İşleme

Ham kamera görüntüsü, çevresel aydınlatma değişimlerine karşı dayanıklılığı artırmak

amacıyla öncelikle LAB renk uzayına dönüştürülmektedir. Bu uzayda, L (parlaklık) kanalı

üzerinde uygulanan CLAHE (Contrast Limited Adaptive Histogram Equalization) yöntemiyle,

gölgeli veya düşük kontrastlı aydınlatma koşullarında renkli bantların belirginliği artırılmaktadır. İyileştirilen görüntü tekrar BGR renk uzayına dönüştürülerek, maskeleme

aşamasının girdi parametresi olarak hazır hale getirilmektedir.

### 6.4.2 HSV Renk Maskeleme

Yol sınırlarını oluşturan bantların tespiti için HSV renk uzayı kullanılmıştır. Geliştirme

sürecinde kırmızı, pembe, mavi ve yeşil renkli bantlar üzerinde kapsamlı saha testleri

gerçekleştirilmiş; aydınlatma değişimlerine karşı en yüksek ayırt ediciliği ve kararlılığı

sağlayan mavi renkli bantlar final tasarımı için standart olarak belirlenmiştir. Mavi bandın

tespitine yönelik HSV eşik değerleri, geliştirilen color_tune.py adlı kalibrasyon aracı

kullanılarak her zemin ve aydınlatma kombinasyonunda deneysel olarak kalibre edilmiştir.

Maskeleme işleminin ardından, görüntü üzerinde kalan rastgele gürültülerin temizlenmesi için

morfolojik açma (opening) ve kapama (closing) işlemleri uygulanarak temiz bir maske çıktısı

elde edilmiştir. Ham kamera görüntüsü ve elde edilen HSV maske çıktısı karşılaştırmalı olarak

Şekil 11’de verilmiştir. Kullanılan final eşik değerleri Tablo 3'te sunulmuştur.

Tablo 3. Şerit Takip Algoritmasında Test Edilen HSV Renk Aralıkları ve Final Seçimi

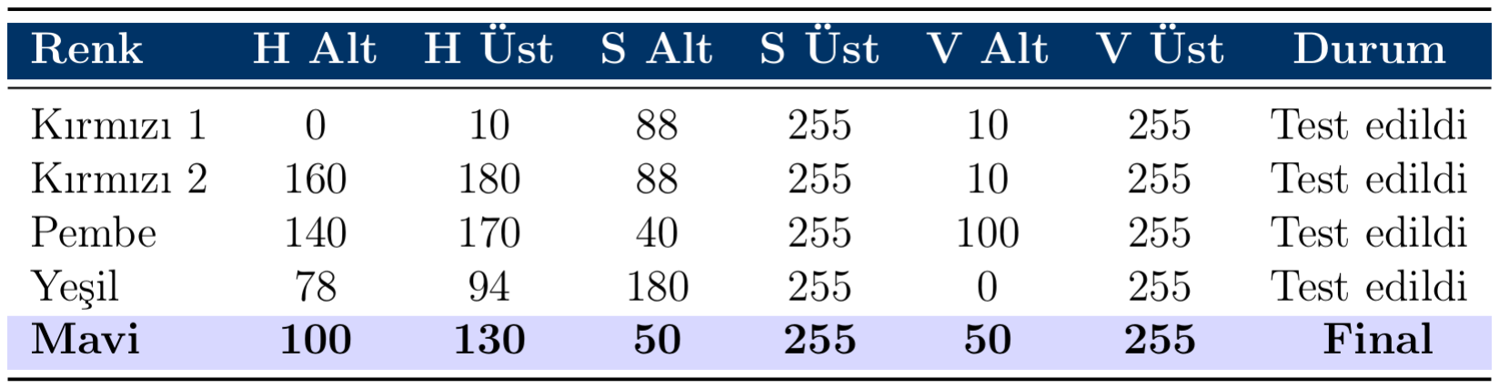
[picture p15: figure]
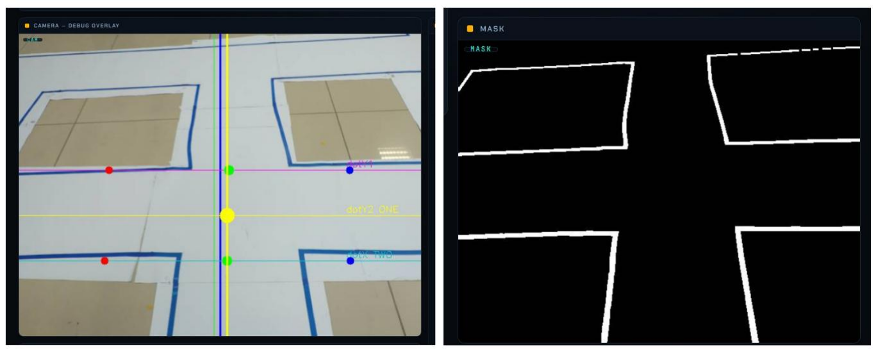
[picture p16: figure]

Şekil 11. Ham görüntü ve HSV maske çıktısı

### 6.4.3 Üç Bant Bölgesi Analizi

Şerit tespiti, bilgisayarlı görüde 'İlgi Bölgesi' (ROI - Region of Interest) tabanlı kademeli bir

yaklaşımla, görüntü yüksekliği boyunca belirlenen üç farklı yatay bant bölgesinde

gerçekleştirilmektedir. Kameranın zemine göre montaj açısı ve oluşan perspektif projeksiyonu

dikkate alınarak optimize edilen bu hiyerarşik yapı; aracın hem uzun mesafe yol planlamasında

hem de yakın mesafe hassas şerit takibinde yüksek başarımla çalışmasını sağlamaktadır. Şekil

12'de görselleştirilen bu bant dağılımı, sistemin geometrik algılama mimarisini ve bölgelerin

koordinasyonlu çalışma prensibini açıkça ortaya koymaktadır.

Şekil 12. Şerit tespiti için kullanılan üç bantlı bölge analizi ve ROI (İlgi Bölgesi) dağılımı.

Görüntü üzerindeki bantların işlevsel dağılımında; %45 yükseklikte konumlanan dotY1 bandı

kavşak öncesi doğrulama ve uzaktan yol ayrımı tespiti için, %60 yükseklikte konumlanan

dotY2 bandı tek şerit takibi ve kavşak giriş/çıkış analizleri için referans bölgesidir. %75

yükseklikte konumlanan dotX bandı ise araç önünde, doğrudan sürüşü yönlendiren çift şerit

takibi ve yakın mesafe merkezleme (fine-tuning) işlemleri için kullanılan temel kontrol

bandıdır. Algoritma, her bant bölgesinde maskelenmiş görüntünün sol ve sağ yarılarındaki

piksel kütlelerinin moment analizi (centroid calculation) üzerinden yol merkezini

hesaplamaktadır. Çift şerit tespit edildiği durumlarda merkez, iki şeridin orta noktası olarak;

tek şerit durumunda ise bilinen yol genişliği (160 piksel) referans alınarak kestirimci yöntemle

belirlenmektedir. Bu hiyerarşik yöntem, Şekil 12’de sınırları belirlenen bölgelerin eş zamanlı

işlenmesi sayesinde aracın dinamik hareketlerinde şerit kayıplarını minimuma indirmekte ve

yol takibini stabil hale getirmektedir.

### 6.4.4 Hata Hesaplama ve PID Kontrolü

Yol merkezi ile görüntü merkezi arasındaki piksel farkı, anlık hata değeri olarak

tanımlanmaktadır. Bu hata sinyali, yüksek frekanslı salınımları engellemek amacıyla 0,65 katsayılı üstel hareketli ortalama filtresiyle (EMA) düzgünleştirilmektedir. İşlenen hata sinyali,

aracın yönelme açısını (yaw rate) belirleyen wz hız komutunu üretmek üzere PID kontrolörüne

aktarılmaktadır.

PID çıkışı, UART protokolü üzerinden STM32 mikrodenetleyicisine iletilerek tekerleklerin

diferansiyel hızlarına dönüştürülmektedir. Kontrol parametrelerinin optimizasyonu, saha

testleri sırasında gerçekleştirilen iteratif deneme-yanılma süreçleri ile sağlanmış; aracın farklı

zemin ve aydınlatma koşullarında en kararlı seyir tepkisini verdiği katsayılar belirlenmiştir. Bu

süreç sonucunda elde edilen ve sistem kararlılığını sağlayan PID parametreleri Tablo 4'te

sunulmuştur.

Tablo 4. Şerit takip sisteminde kullanılan PID kontrolör parametreleri

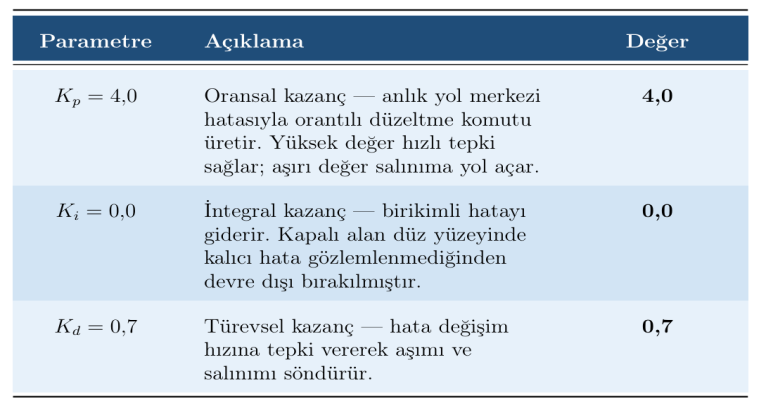
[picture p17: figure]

### 6.5 Kavşak Tespiti ve Sonlu Durum Makinesi (FSM)

Otonom aracın kavşaklarda doğru kararlar verebilmesi için sensörlerden gelen anlık görüntü

verileri üzerinde çalışan bir Sonlu Durum Makinesi (Finite State Machine — FSM) yapısı

kurgulanmıştır. Sistem; şerit takibi, kavşak algılama, dönüş manevrası, şerit hizalama ve hedefe

ulaşma gibi birbirini izleyen durumlar arasında geçiş yaparak otonom sürüşü deterministik

biçimde yönetmektedir. Kavşak tespiti, görüntü işleme işlem hattındaki dotY1 ve dotY2 bant

bölgelerindeki sol ve sağ şerit varlığına göre üç tipe ayrılmaktadır. Her iki şeridin kaybolduğu

durum BOTH, yalnızca sol şeridin kaybolduğu durum LEFT_ONLY, yalnızca sağ şeridin

kaybolduğu durum ise RIGHT_ONLY olarak sınıflandırılmaktadır. Anlık gürültülerden

kaynaklanan yanlış tetiklemeleri önlemek amacıyla mimariye bir histerezis sayacı mekanizması

uygulanmış; kavşak koşulunun art arda belirli sayıda kare boyunca kararlı şekilde

gözlemlenmesi durumunda kavşak tespiti resmi olarak onaylanmaktadır.

Sistem toplamda sekiz temel durumdan oluşmaktadır. STATE_FOLLOW durumunda araç PID

kontrolörüyle şerit merkezini takip ederek ilerlemektedir. Kavşak tespiti onaylandığında

STATE_FORWARD_GAP durumuna geçilmekte ve araç kısa bir süre sabit hızda ilerleyerek

kavşak merkezine güvenli bir şekilde konumlanmaktadır. Ardından STATE_TURN

durumunda, hedeflenen yaw açısına göre dönüş manevrası gerçekleştirilmektedir. Dönüş

tamamlandığında STATE_AFTER_TURN_SIDE durumunda Mecanum tekerleklerin yanal

hareket kabiliyeti aktif olarak kullanılmakta; araç yanal kaymalarını sıfırlayarak kendini yol

merkezine hizalamakta ve tekrar STATE_FOLLOW durumuna geri dönmektedir. Kavşakta

yönelim değiştirmeden düz ilerleme gerektiğinde STATE_STRAIGHT_PASS durumu devreye

girmektedir. Rota görevleri başarıyla tamamlanıp hedef konuma ulaşıldığında STATE_DONE

durumu ile araç güvenli biçimde durdurulmaktadır. Rota planlayıcıdan gelen alternatif bir

güzergahın bulunamadığı kriz anlarında STATE_NO_PATH, U-dönüşü sonrasında güvenli

geri ilerleme senaryolarında ise STATE_UTURN_BACK durumları etkinleştirilerek sistem

kararlılığı korunmaktadır. Sistemin tüm bu durum geçiş mantığı, süreç hiyerarşisini gösteren

FSM akış şeması ile modellenmiştir (Şekil 13).

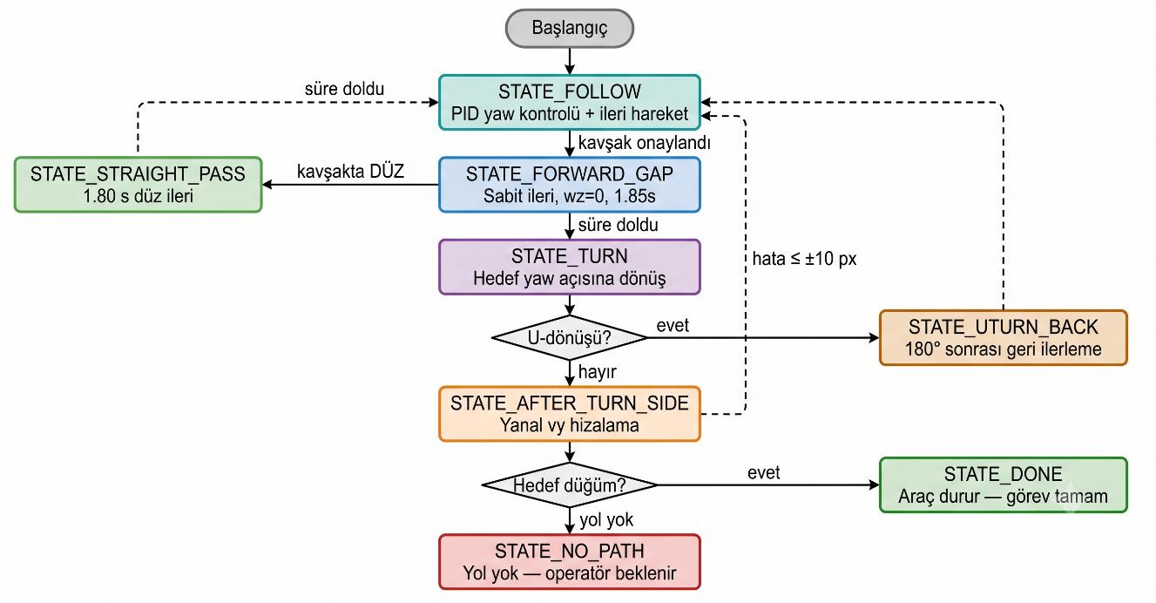
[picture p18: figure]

Şekil 13. Sonlu Durum Makinesi (FSM) Akış Şeması

### 6.6 Graf Tabanlı Rota Navigasyonu

Aracın hedef konuma en verimli şekilde ulaşabilmesi için kapalı alan haritası bir çizge (graph)

yapısına dönüştürülmüş ve rota planlama işlemleri Dijkstra algoritmasıyla gerçekleştirilmiştir.

Harita üzerindeki kavşaklar ve hedef noktalar düğüm (node), bu düğümleri birbirine bağlayan

yol kesimleri ise kenar (edge) olarak tanımlanmıştır. Her kenara, yolun fiziksel uzunluğuna

göre bir maliyet (cost) değeri atanmıştır. Grafik tabanlı harita mimarisi; düğümleri, kenarları ve

örnek bir rota gösterimini içerecek şekilde tasarlanmıştır.

Rota planlama süreci, başlangıç düğümünden hedef düğüme kadar toplam maliyeti en aza

indiren yolun hesaplanması prensibiyle çalışmaktadır. Dijkstra algoritması öncelikli kuyruk

yapısı kullanarak her düğüme olan en kısa mesafeyi sürekli güncellemekte ve nihai rota listesini

oluşturmaktadır. Trafik işareti tespiti veya operatör müdahalesi sonucunda bir kenar

engellendiğinde (örneğin kapalı yol durumu), Dijkstra algoritması dinamik olarak yeniden

çalıştırılarak alternatif güzergah anlık olarak hesaplanmaktadır. Eğer harita üzerinde hiçbir

alternatif güzergah bulunamazsa sistem otomatik olarak STATE_NO_PATH durumuna

geçmekte; koşullar uygunsa U-dönüşü yaparak geri çekilme ve harita üzerinde yeniden

planlama yoluna gitmektedir.

Rota planlayıcı tarafından üretilen tüm üst düzey navigasyon kararları (sola dön, sağa dön, düz

geç, dur) Raspberry Pi 5 ana işlemcisi üzerinde işlenmekte ve elde edilen hız komutları (vx, vy,

wz) olarak UART protokolü üzerinden STM32 mikrodenetleyicisine iletilmektedir.

Bu hiyerarşik yapı sayesinde üst düzey navigasyon ve rota kararları ile alt düzey motor hız

kontrolü birbirinden bağımsız çalışarak sistemin modülerliğini ve işlem hızını artırmaktadır.

### 6.7 Trafik İşareti Tespit Modelinin Eğitimi

Trafik işareti tespiti için YOLOv11s mimarisi tercih edilmiştir. Tek aşamalı nesne dedektörü

olan YOLO ailesi; gerçek zamanlı çıkarım hızı ve yüksek doğruluk dengesiyle gömülü sistem

uygulamalarında yaygın biçimde kullanılmaktadır. Projenin başlangıç aşamasında YOLOv8n

mimarisiyle çalışılmış; ancak Raspberry Pi 5 üzerinde doğrudan yapılan testlerde elde edilen 1-

2 FPS hızının gerçek zamanlı otonom sürüş güvenliği için yetersiz kaldığı görülmüştür. Bu

performans sorunu, kamera görüntüsünün TCP soket protokolü üzerinden bir bilgisayara (PC)

aktarılması ve çıkarım (inference) işlemlerinin yüksek işlem gücüne sahip PC tarafında

gerçekleştirilmesiyle çözülmüştür. Donanım ve haberleşme mimarisinin kararlı hale gelmesinin

ardından, daha yüksek doğruluk değerleri sunan YOLOv11s modeline geçiş yapılmış ve model

150 epoch boyunca eğitime tabi tutulmuştur.

Model eğitimi, Türkiye yol işaretlerini kapsayan açık kaynaklı bir veri seti üzerinde

yürütülmüştür. Toplamda 15.937 görüntü ve 16 sınıftan oluşan bu veri setinin hazırlık

aşamasında, sınıfların dengeli dağılımı ve nesne boyutlarının tespiti için kapsamlı veri analizleri

gerçekleştirilmiştir. Eğitilen veri setine ait sınıf dağılımları ve sınırlayıcı kutu (bounding box)

boyutlarının ilişkisini gösteren yapısal özellikler Şekil 14'te verilmiştir.

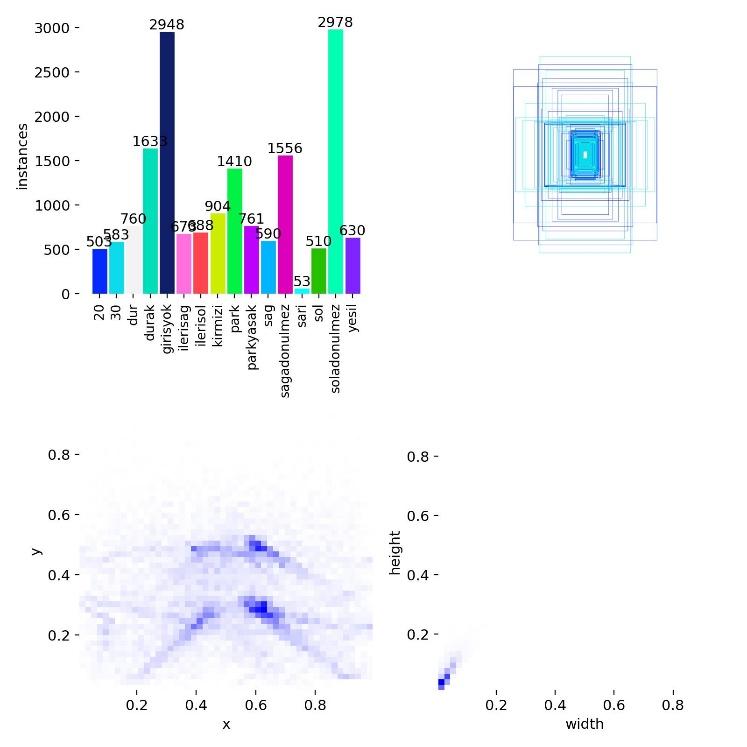
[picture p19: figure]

Şekil 14. Veri seti sınıf dağılımı ve etiket özellikleri grafikleri

Eğitim sürecinde karşılaşılan en kritik teknik problem, sağa dönüş ve sola dönüş işaretlerinin

model tarafından birbirine karıştırılması olmuştur. Standart veri artırma (data augmentation)

işlemlerinde varsayılan olarak uygulanan yatay çevirme (horizontal flip) yöntemi, yön bilgisi

taşıyan bu işaretlerin aynalanmasına ve dolayısıyla modelin yanlış etiketlerle beslenmesine yol

açmıştır. Bu geometrik karmaşa, eğitim konfigürasyon dosyasındaki yatay çevirme

parametresinin etkisizleştirilmesi (fliplr=0.0) ile çözülmüştür. Bu optimizasyonun ardından

model, sağa ve sola dönüş işaretlerini yüksek güvenilirlikle ayırt edebilir hale gelmiştir. 150

epoch boyunca sürdürülen eğitimde, eğitim ve doğrulama kayıplarının kararlı bir şekilde

yakınsadığı; Precision, Recall ve mAP değerlerinin sürekli olarak optimize olduğu

gözlemlenmiştir. Modelin genel eğitim performansı ve metrik değişimleri Şekil 15'te

sunulmuştur.

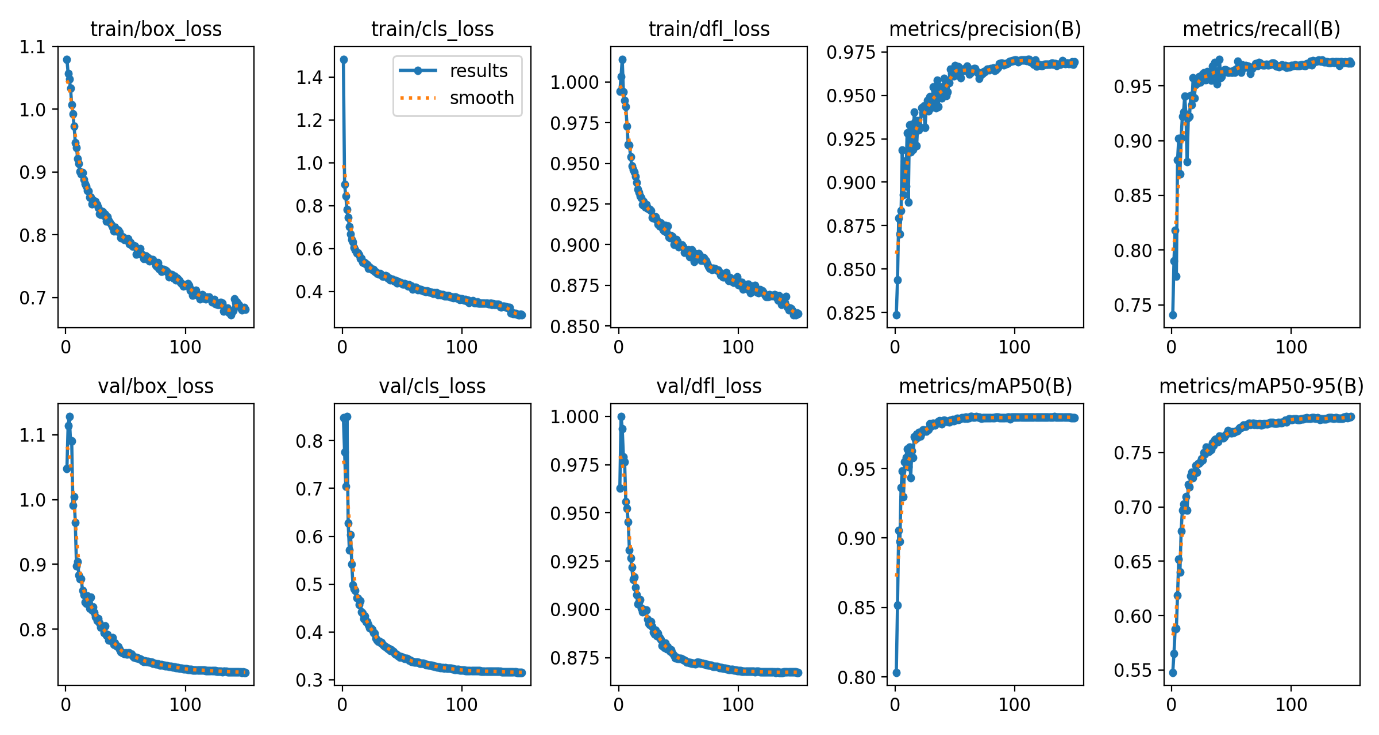
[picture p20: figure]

Şekil 15. 150 epoch boyunca eğitim ve doğrulama süreci kayıp ve başarı metrikleri grafiği

Eğitim sonucunda elde edilen performans metrikleri incelendiğinde, modelin oldukça yüksek

bir başarıma ulaştığı görülmektedir. Sınıfların kendi aralarındaki doğru tahmin ve hata

oranlarını çaprazlama olarak gösteren normalize edilmiş karmaşıklık matrisi sonuçları Şekil

16'da sunulmuştur. Matris incelendiğinde, tüm sınıflarda doğru tespit oranını gösteren köşegen

değerlerin 0.93 ile 1.00 arasında seyrettiği, sınıflar arası karışıklığın son derece sınırlı kaldığı

tescillenmiştir.

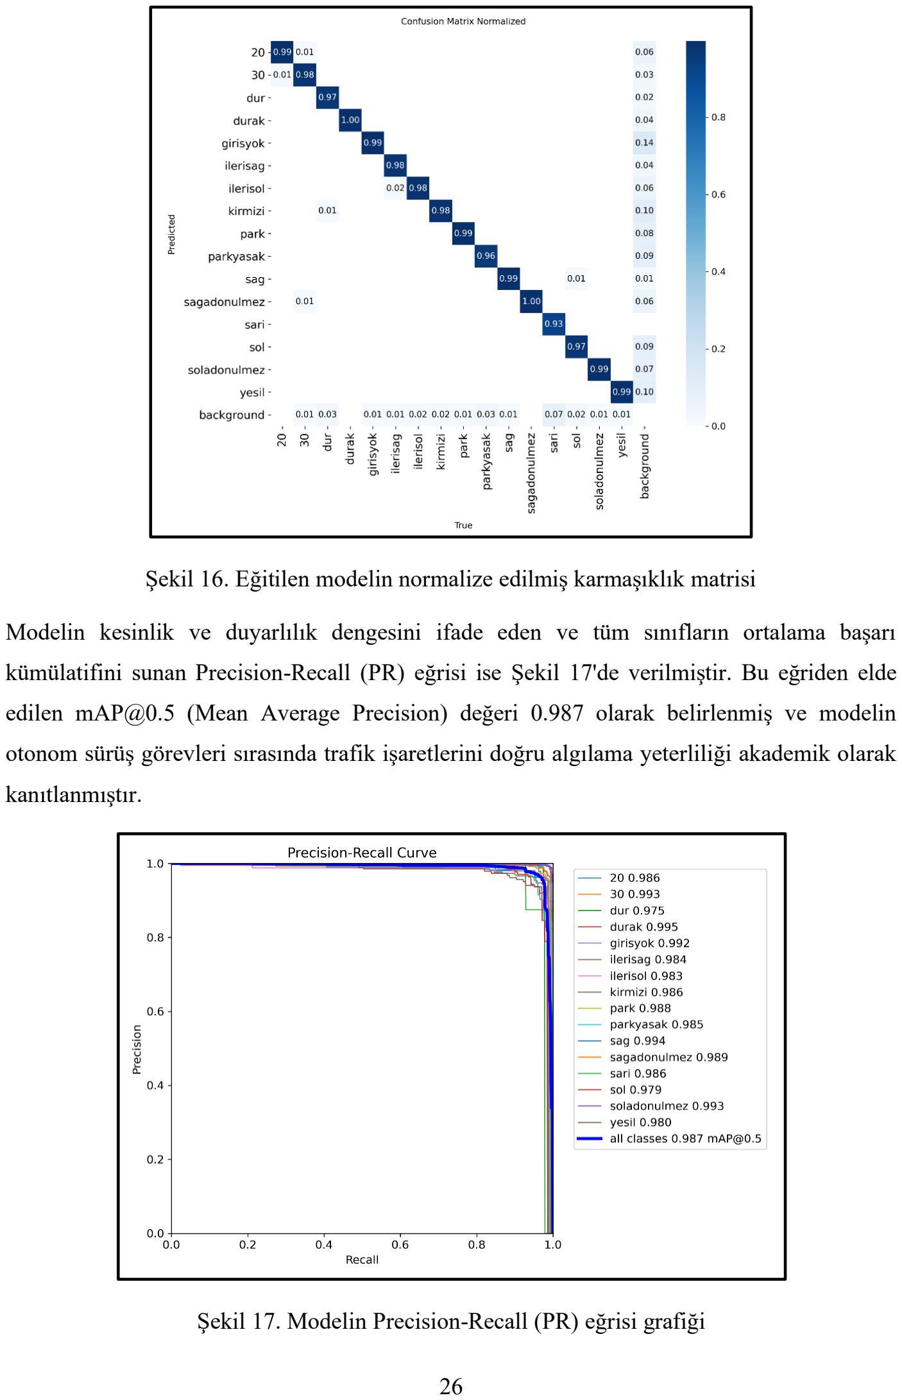
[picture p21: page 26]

Şekil 16. Eğitilen modelin normalize edilmiş karmaşıklık matrisi

Modelin kesinlik ve duyarlılık dengesini ifade eden ve tüm sınıfların ortalama başarı

kümülatifini sunan Precision-Recall (PR) eğrisi ise Şekil 17'de verilmiştir. Bu eğriden elde

edilen mAP@0.5 (Mean Average Precision) değeri 0.987 olarak belirlenmiş ve modelin

otonom sürüş görevleri sırasında trafik işaretlerini doğru algılama yeterliliği akademik olarak

kanıtlanmıştır.

Şekil 17. Modelin Precision-Recall (PR) eğrisi grafiği

Tablo 6. YOLOv11s Model Eğitimi Performans Sonuçları

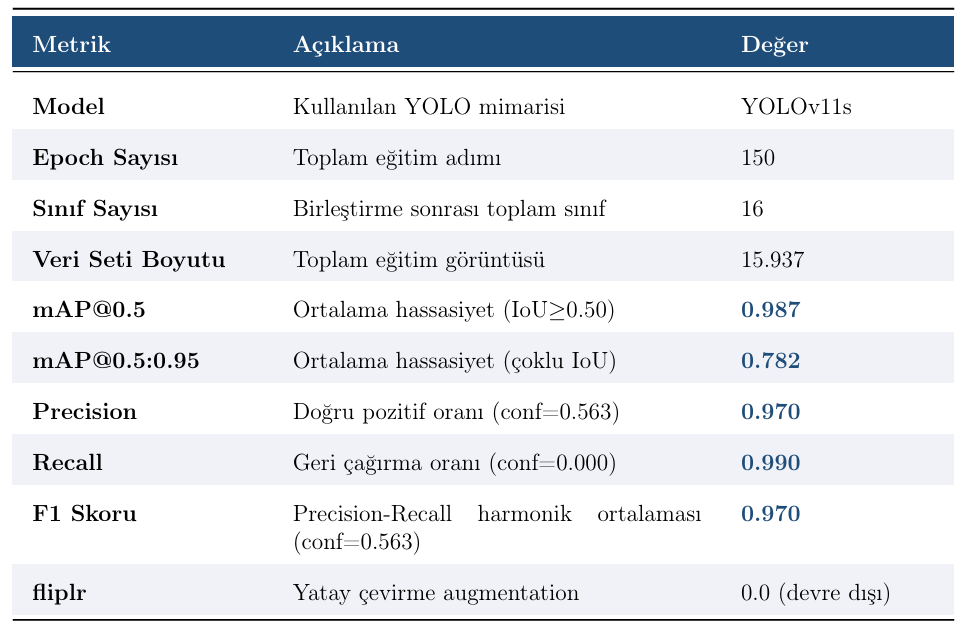
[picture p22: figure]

### 6.8 Engel Tespiti

Engel tespiti; maliyetli sensör altyapılarına başvurulmaksızın, araç üzerinde mevcut olan

kamera donanımından maksimum düzeyde yararlanılarak ve ultrasonik mesafe sensörleri ile

desteklenerek gerçekleştirilmektedir. Geliştirilen yöntem, yol bölgesi içindeki yabancı

nesnelerin tespit edilmesine yönelik negatif alan analizi prensibine ve donanımsal sensör

füzyonuna dayanmaktadır.

Algoritma öncelikle HSV renk maskeleme yöntemiyle yol hatlarını belirlemekte ve bu bantların

sütun bazlı dağılımından yararlanarak güvenli yol sınırlarını hesaplamaktadır. Yol içi güvenli

bölge; sol bandın bitiş noktasından BAND_MARGIN (40 piksel) içeri dalınan alan ile sağ

bandın başlangıç noktasından BAND_MARGIN (40 piksel) içeri girilen alan arasındaki

koordinat düzlemi olarak tanımlanmaktadır. Bu dinamik bölge içerisinde yer alan ve yol bandı

rengine sahip olmayan pikseller, sistem tarafından potansiyel engel adayı olarak

değerlendirilmektedir.

Yanlış pozitif tespitleri minimuma indirmek amacıyla zemin rengi de maskeleme işlemine dahil

edilmiştir. Açık zemin rengi; düşük doygunluk ve yüksek parlaklık değerleri filtrelenerek ayrı

bir HSV maskesiyle tespit edilmekte ve engel adayları arasından ayıklanmaktadır.

Kalan piksel kümesi üzerinde gürültülerin temizlenmesi amacıyla morfolojik açma ve kapama

işlemleri uygulandıktan sonra kontur analizi gerçekleştirilmektedir. Hesaplanan kontur

alanının, belirlenen 5000 piksel² değerindeki asgari engel boyutu sınırını aşması durumunda,

ilgili piksel kümesi mutlak bir engel olarak değerlendirilmekte ve çevreleyen bir kutu içine

alınmaktadır. Geliştirilen algoritmanın test esnasındaki yol sınırları, kontur tespiti ve sınırlayıcı

kutu (bounding box) çıktısı Şekil 18'de sunulmuştur.

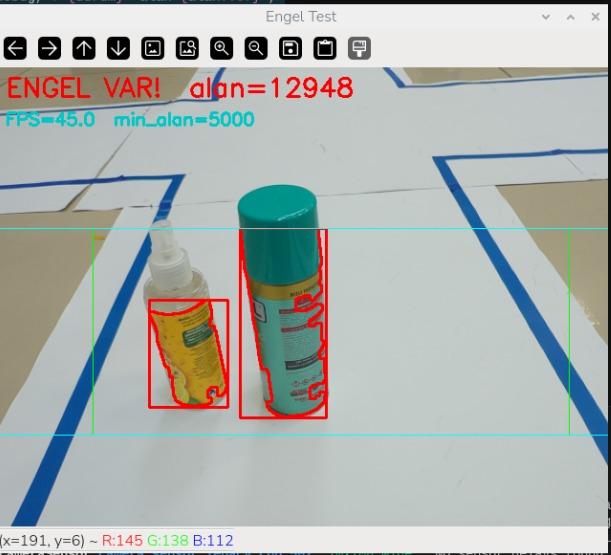
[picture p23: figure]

Şekil 18. Engel tespit algoritması çıktısı — yol sınırları, kontur ve sınırlayıcı kutu gösterimi

Sistemin güvenilirliğini ve sürüş emniyetini katmanlı hale getirmek amacıyla, kamera verileri

ile aracın ön bölgesine yerleştirilen AJ-SR04M ultrasonik mesafe sensörü arasında aktif bir çift

doğrulama ve sensör füzyonu mekanizması uygulanmıştır. Bu hiyerarşik yaklaşıma göre;

kamera tabanlı negatif alan analizinin ürettiği engel tespiti çıktısı ile ultrasonik sensörden alınan

donanımsal mesafe verisi eş zamanlı olarak eşleştirilmektedir. Kamera algoritması bir engel

konturu belirlediğinde, eş zamanlı olarak ultrasonik sensörün kritik mesafe eşiği (30 cm) kontrol edilmektedir. İki farklı veri kaynağının da engeli onaylamasıyla birlikte Sonlu Durum

Makinesi (FSM) anlık olarak acil durma durumuna geçmekte ve STM32 kontrolcüsüne

motorları kilitleyen durma komutu iletilmektedir. Bu füzyon mimarisi; kameranın anlık

aydınlatma değişimlerinden kaynaklı hatalı çıkarımlar yapmasını engellediği gibi, ultrasonik

sensörün dar algılama açısı dezavantajını da ortadan kaldırarak sistemi çevresel gürültülere

karşı tamamen kararlı hale getirmiştir.

### 6.9 Sistem Entegrasyonu ve Testler

Proje kapsamında geliştirilen tüm yazılım ve donanım bileşenleri öncelikle alt sistem bazında

bağımsız olarak test edilmiş; ardından kademeli entegrasyon metodolojisiyle bir araya getirilmiştir. Düzenli saha çalışmaları ve sistemli hata ayıklama süreçleriyle yürütülen

entegrasyon aşamasında karşılaşılan en kritik boyutu, ayrı geliştirilen modüllerin eş zamanlı

çalıştırılması sırasında ortaya çıkan yazılımsal uyumsuzluklar oluşturmuştur. Laboratuvar

ortamında bağımsız olarak hatasız çalışan bileşenlerin, dinamik çalışma ortamında birbirlerinin

çalışma zamanlamasını etkilediği gözlemlenmiştir. Bu durum, modüllerin hiyerarşik olarak

teker teker ana sisteme entegre edilmesi ve her adımda regresyon testlerinin uygulanmasıyla

aşılmıştır. Ayrıca, yoğun test döngüleri ve fiziksel sarsıntılar neticesinde prototip kablo

bağlantılarında meydana gelen temassızlıklar ve kopmalar, kritik noktaların endüstriyel

standartlarda yeniden lehimlenmesi ve ısıyla daralan makaronlarla izole edilmesi suretiyle

kalıcı olarak çözülmüştür.

Donanımsal entegrasyon esnasında karşılaşılan bir diğer önemli problem, MPU6050 Atalet Ölçüm Birimi (IMU) sensörünün I²C veri yolu üzerinden anlık yüksek akım çekimlerine bağlı

elektriksel gürültülerden ötürü kilitlenmesi ve aracın sapma açısı (yaw) stabilizasyonunu

kesintiye uğratması olmuştur. Elektromanyetik girişimi ve şasi sarsıntılarını minimize etmek

adına sensörün şasi üzerindeki fiziksel konumu optimize edilmiş, veri hatları güç hatlarından

fiziksel olarak yalıtılarak kablo mimarisi yeniden düzenlenmiş ve iletişim kararlılığı

sağlanmıştır. Yazılımsal tarafta ise şerit takip algoritmasının ilk tasarımında tek bir şerit

çizgisinin tespit edilip diğer şeridin geometrik olarak tahmin edilmesi prensibi

benimsenmişken, saha testlerinde keskin dönüşlerde ve aydınlatma değişimlerinde bu

yaklaşımın yüksek yönelim hatalarına sebep olduğu saptanmıştır. Bu doğrultuda mimari köklü

bir değişikliğe uğratılarak, aracın görüş alanında çift şerit doğrulayana kadar Mecanum

tekerleklerin yanal (vy) hareket kabiliyetini kullanarak kendini otomatik olarak merkezlemesi

sağlanmış ve çift şerit verisi teyit edilmeden kontrol döngüsünün ileri sürüş komutu üretmesi

engellenmiştir. Bu stratejik değişiklik, şerit takip kararlılığını maksimum seviyeye çıkarmıştır.

Nesne tespiti modelinin (YOLOv11s) Raspberry Pi 5 üzerinde doğrudan çalıştırılması

esnasında işlemci darboğazı oluşmuş ve işlem hızı 1-2 FPS seviyelerine düşmüştür. Otonom

sürüş güvenliğini tehdit eden bu performans sorunu, kamera görüntülerinin TCP soket

protokolü üzerinden yüksek işlem gücüne sahip bir bilgisayara gerçek zamanlı aktarılması ve

çıkarım sonuçlarının milisaniyeler içerisinde geri alınmasıyla çözülmüştür.

Ek olarak, test sahasındaki zemin parlamalarının ve yabancı nesne yansımalarının engel tespiti

maskesini bozması problemi; zemine özgü HSV renk uzayı eşiklerinin ayrıca kalibre edilmesi

ve ana görüntü işleme hattına bir zemin ayıklama maskesi olarak entegrasyonuyla aşılmıştır.

Tüm entegrasyon sorunlarının başarıyla optimize edilmesinin ardından gerçekleştirilen nihai

saha testlerinde, otonom araç tanımlanan tüm senaryoları ve navigasyon görevlerini hatasız bir

şekilde tamamlamıştır. Modüller arası veri trafiğini yöneten UART haberleşme hattında test

süresi boyunca herhangi bir paket kaybı yaşanmamış ve sistem üzerinde yer alan 3S LiPo

batarya bloğu ile tüm donanım bileşenleri aktif haldeyken kesintisiz 45 dakika boyunca kararlı

çalışma süresi elde edilmiştir. Gerçekleştirilen sistem testlerine ait genel performans

parametreleri Tablo 8'de özetlenmiştir.

Tablo 8. Otonom Sistem Entegrasyonu ve Saha Testi Sonuçları

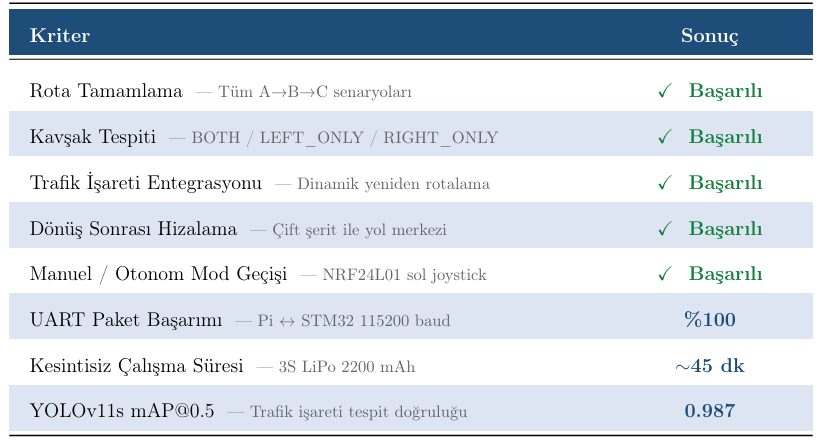
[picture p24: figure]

### 7. SONUÇLAR

Bu çalışmada tasarımı, üretimi ve yazılımsal altyapısı özgün olarak gerçekleştirilen Mecanum

tekerlekli otonom robot platformunun saha testlerinden elde edilen tüm bulgular, çalışmanın

başlangıcında belirlenen teknik ve akademik hedefler doğrultusunda kapsamlı bir şekilde

değerlendirilmiştir. Raporun önceki bölümlerinde detaylandırılan entegrasyon süreçleri,

karşılaşılan mekanik, elektriksel ve yazılımsal problemler ile bu problemlere üretilen

mühendislik çözümleri, platformun nihai performans çıktılarının temelini oluşturmuştur. Elde

edilen deneysel sonuçlar, sistemin alt modüllerinin sadece teoride değil, dinamik ve değişken

saha koşullarında da birbirleriyle yüksek uyumla çalışabildiğini kanıtlamıştır.

Şerit takibi hedefi kapsamında, HSV renk uzayı maskeleme ve üstel hareketli ortalama (EMA)

filtresiyle düzgünleştirilmiş PID kontrolör mimarisi, kapalı alan zemininde farklı aydınlatma

koşullarında son derece kararlı sonuçlar üretmiştir. Görüntü işleme döngüsünün saniyede 22 ila

25 kare (FPS) hızında çalışması, projenin başında asgari sınır olarak belirlenen 20 FPS hedefini

başarıyla karşılamıştır. Saha testlerinde keskin viraj ve kavşak manevralarının ardından

Mecanum tekerleklerin sağladığı yanal (vy) hareket kabiliyeti aktif olarak işletilmiş, araç çift

şerit doğrulaması yapana kadar kendini yanal olarak kaydırıp şerit merkezine başarıyla

hizalamıştır. Bu esnada ölçülen yol merkezi hatası, hedeflenen piksel sınırının içinde kalarak

sistemin sürüş hassasiyetini tescillemiştir.

Navigasyon ve üst düzey karar alma mekanizması doğrultusunda kurgulanan Dijkstra

algoritmasına dayalı çizge (graf) tabanlı rota planlayıcı, tanımlanan tüm karmaşık senaryolarda

başlangıç noktasından hedef noktaya kesintisiz ulaşımı mümkün kılmıştır. Görüntü işleme

işlem hattından gelen tek şerit, çift şerit ve kavşak durumları Sonlu Durum Makinesi (FSM)

tarafından güvenilir biçimde ayırt edilmiştir. Derin öğrenme tabanlı algılama modülünden elde

edilen anlık trafik işareti verilerine göre dinamik olarak yeniden rota planlama (re-routing)

işlevi deneysel sahada doğrulanmış; çıkmaz sokak veya engellenmiş yol senaryolarında

sistemin U-dönüşü gerçekleştirerek alternatif güvenli güzergahlara yönelme kabiliyeti

kararlılıkla çalışmıştır.

Trafik işareti tespiti hedefi kapsamında eğitilen YOLOv11s modeli, veri setinin yapısal

özniteliklerini gösteren Şekil 14 ve eğitim sürecindeki yakınsamayı sunan Şekil 15’teki

metrikler doğrultusunda %98,7 mAP@0.5 değerine ulaşarak, başlangıçta öngörülen %85 başarı

hedefini önemli ölçüde aşmıştır.

Şekil 16'da paylaşılan normalize edilmiş karmaşıklık matrisinde tüm sınıflarda köşegen

değerlerinin 0,93 ile 1,00 arasında kalması, sınıflar arası karışıklığın son derece sınırlı kaldığını

doğrulamıştır. Şekil 17'deki Precision-Recall (PR) eğrisiyle de başarımı tescillenen bu model

sayesinde, tanınan işaretlerin FSM durum geçişlerine ve dolayısıyla araç davranışına anlık

olarak yansıtılması sahada tam başarıyla doğrulanmıştır. Emniyet sınırlarını belirleyen engel

tespiti çalışmaları kapsamında ise yol bölgesi içindeki yabancı nesneler negatif alan ve kontur

analizi yöntemleriyle kamera üzerinden kararlılıkla ayırt edilmiştir. Kamera tabanlı bu görsel

algılama mekanizması, ön bölgeye yerleştirilen ultrasonik mesafe sensörünün donanımsal

mesafe verileriyle gerçek zamanlı olarak füzyona tabi tutulmuş; iki farklı kaynak tarafından

onaylanan engeller karşısında FSM'in anlık olarak acil durma durumuna geçerek motorları

kilitlemesi sağlanmış ve engel algılama güvenilirliği maksimuma çıkarılmıştır.

Sistem entegrasyonu ve alt-üst seviye donanım hiyerarşisi kapsamında, Raspberry Pi 5 ana

işlemcisi ile STM32 mikrodenetleyicisi arasında UART protokolü üzerinden yürütülen çift

yönlü veri trafiğinde test süresi boyunca herhangi bir paket kaybı yaşanmamış ve %100

haberleşme başarım oranı elde edilmiştir. Enerji yönetimi safhasında, prototip üzerinde yer alan

3S LiPo 2200 mAh batarya bloğu, tüm donanımsal bileşenler ve algoritmalar tam yük altında

aktif haldeyken kesintisiz 45 dakika çalışma süresi sunarak belirlenen 30 dakika sınırını geride

bırakmıştır. Gerçekleştirilen tüm bu sistem entegrasyonu, donanım modifikasyonları ve işlevsel

saha testi sonuçlarına ait genel performans parametreleri, Bölüm 6.9'da sunulan Tablo 8'de tüm

teknik dökümüyle özetlenmiştir.

Projenin olumlu yönleri genel bir perspektifle değerlendirildiğinde; LiDAR veya benzeri

yüksek maliyetli sensör altyapılarına başvurulmaksızın, optimize edilmiş bilgisayarlı görü

algoritmaları ve düşük maliyetli donanımlarla kapalı alan otonom navigasyonunun başarıyla

gerçeklenebileceği kanıtlanmıştır. Dijkstra tabanlı dinamik rota planlama mimarisi esnek ve

kararlı bir navigasyon altyapısı sunarken, YOLOv11s modelinin yüksek doğruluğu çevresel

farkındalığı üst seviyeye taşımıştır. Bu çalışma; gömülü sistemler, bilgisayarlı görü, yapay

zeka, mekatronik tasarım ve gerçek zamanlı kontrol gibi farklı mühendislik disiplinlerini tek

bir platformda harmanlayarak, lisans eğitimi boyunca kazanılan teorik bilgi ve becerilerin

bütüncül ve somut bir mühendislik uygulamasına yansıtılmasına olanak tanımıştır. Projenin

kısıtları ve olumsuz yönleri açısından ise, YOLO tabanlı trafik işareti çıkarımının Raspberry Pi

5'in işlemci darboğazı nedeniyle harici bir bilgisayara (PC) bağımlı olarak TCP soket protokolü

üzerinden yürütülmesi ve motor kontrolünde tekerlek enkoderi geri besleme mekanizmasının henüz tam zamanlı kapalı çevrim olarak devreye alınamamış olması temel eksiklikler ve

geliştirmeye açık alanlar olarak not edilmiştir.

İleriye dönük hedefler kapsamında öncelikle tekerlek enkoderlerinden alınacak odometri

verileriyle motor hız kontrolörünün kapalı çevrim mimariyle güçlendirilmesi ve sürüş

hassasiyetinin artırılması planlanmaktadır. Donanımsal taraftaki en temel radikal değişiklik

olarak, Raspberry Pi 5 ana işlemcisinin yerini NVIDIA Jetson serisi gibi üzerinde entegre grafik

işlem birimi (GPU) barındıran gömülü hesaplama platformlarına bırakması hedeflenmektedir.

Bu donanım geçişi; YOLO trafik işareti çıkarımını, şerit takibini ve navigasyon karar alma

süreçlerini tek bir gömülü kart üzerinde gerçek zamanlı olarak yürütmeyi mümkün kılacak ve

mevcut PC bağımlılığını tamamen ortadan kaldıracaktır. Ek olarak, platforma entegre edilecek

bir LiDAR sensörüyle eş zamanlı konumlandırma ve haritalama (SLAM) kabiliyetinin

kazandırılması ile daha hassas engel tespiti yapılması öngörülmektedir. Orta ve uzun vadeli

vizyonda ise, sisteme GPS modülünün entegre edilmesiyle platformun açık alan otonom navigasyon senaryolarına uyarlanması ve TEKNOFEST İnsansız Kara Aracı (İKA) gibi ulusal

ve uluslararası teknoloji yarışmalarına katılım sağlanması temel hedef olarak belirlenmiştir.

### 8. KAYNAKLAR

[1] R. Siegwart, I. R. Nourbakhsh, and D. Scaramuzza, Introduction to Autonomous Mobile

Robots, 2nd ed. MIT Press, 2011.

[2] R. C. Gonzalez and R. E. Woods, Digital Image Processing, 4th ed. Pearson, 2018.
[3] J. Redmon, S. Divvala, R. Girshick, and A. Farhadi, "You Only Look Once: Unified, Real-

Time Object Detection," IEEE Conference on Computer Vision and Pattern Recognition

(CVPR), pp. 779-788, 2016.

[4] E. W. Dijkstra, "A note on two problems in connexion with graphs," Numerische

Mathematik, vol. 1, pp. 269–271, 1959.

[5] Robotistan, "Raspberry Pi 5 8GB Geliştirme Kartı Teknik Özellikleri," 2024. [Çevrimiçi].

Erişilebilir: https://www.robotistan.com/raspberry-pi-5-8gb [Erişim Tarihi: 08-Haz-2026].

[6] STMicroelectronics, "STM32F407 Discovery Kit User Manual and Technical

Documentation," 2023. [Çevrimiçi]. Erişilebilir: https://www.robotistan.com/stm32f4-

discovery [Erişim Tarihi: 08-Haz-2026].

[7] Raspberry Pi Foundation, "Raspberry Pi Camera Module 3 Wide Angle Datasheet," 2023.

[Çevrimiçi]. Erişilebilir: https://market.samm.com/raspberry-pi-kamera-3-genis-aci [Erişim

Tarihi: 08-Haz-2026].

[8] JSN, "AJ-SR04M Integrated Waterproof Ultrasonic Distance Measuring Module

Datasheet," 2022. [Çevrimiçi]. Erişilebilir: https://www.robotistan.com/aj-sr04m-su-gecirmez-

ultrasonik-sensor [Erişim Tarihi: 08-Haz-2026].

[9] Infineon Technologies, "BTS7960B High Current PN Half Bridge Motor Driver Datasheet,"

2018. [Çevrimiçi]. Erişilebilir: https://www.robotistan.com/bts7960b-20-amper-motor-surucu-

karti [Erişim Tarihi: 08-Haz-2026].

[10] Matek Systems, "PDB-XT60 with BEC 5V & 12V Power Distribution Board User Guide,"

2021. [Çevrimiçi]. Erişilebilir: https://www.direnc.net/pdb-xt60-w/bec-guc-dagitim-karti

[Erişim Tarihi: 08-Haz-2026].

[11] Nordic Semiconductor, "nRF24L01+ Single Chip 2.4GHz Transceiver Product

Specification," 2019. [Çevrimiçi]. Erişilebilir: https://www.robotistan.com/wireless-nrf24l01-

24ghz-transceiver-module [Erişim Tarihi: 08-Haz-2026].

[12] Transducers & Controllers, "XH-M403 DC-DC Digital Voltage Regulator Module Guide,"

2020. [Çevrimiçi]. Erişilebilir: https://robiz.net/xhm403 [Erişim Tarihi: 08-Haz-2026].

[13] T. T. Nguyen, J. Spehr, S. Zug, and D. H. Nguyen, "A Survey on Vision-Based Lane

Detection and Tracking for Autonomous Vehicles," IEEE Transactions on Intelligent

Transportation Systems, vol. 23, no. 8, pp. 10985-11007, 2022.

[14] C. Badue et al., "Self-Driving Cars: A Survey," Expert Systems with Applications, vol.

165, 113816, 2021.

[15] A. G. Howard et al., "MobileNetV2: Inverted Residuals and Linear Bottlenecks,"

Proceedings of the IEEE Conference on Computer Vision and Pattern Recognition (CVPR), pp.

4510-4520, 2018.

[16] L. E. Parker, "Path Planning for Mobile Robots: A Survey," IEEE Transactions on

Robotics and Automation, vol. 18, no. 2, pp. 157-178, 2002.

[17] S. Kato et al., "Autoware on Board: Enabling Autonomous Vehicles with Embedded

Systems," Proceedings of the 2018 ACM/IEEE 9th International Conference on Cyber-Physical

Systems (ICCPS), pp. 287-296, 2018.

EKLER

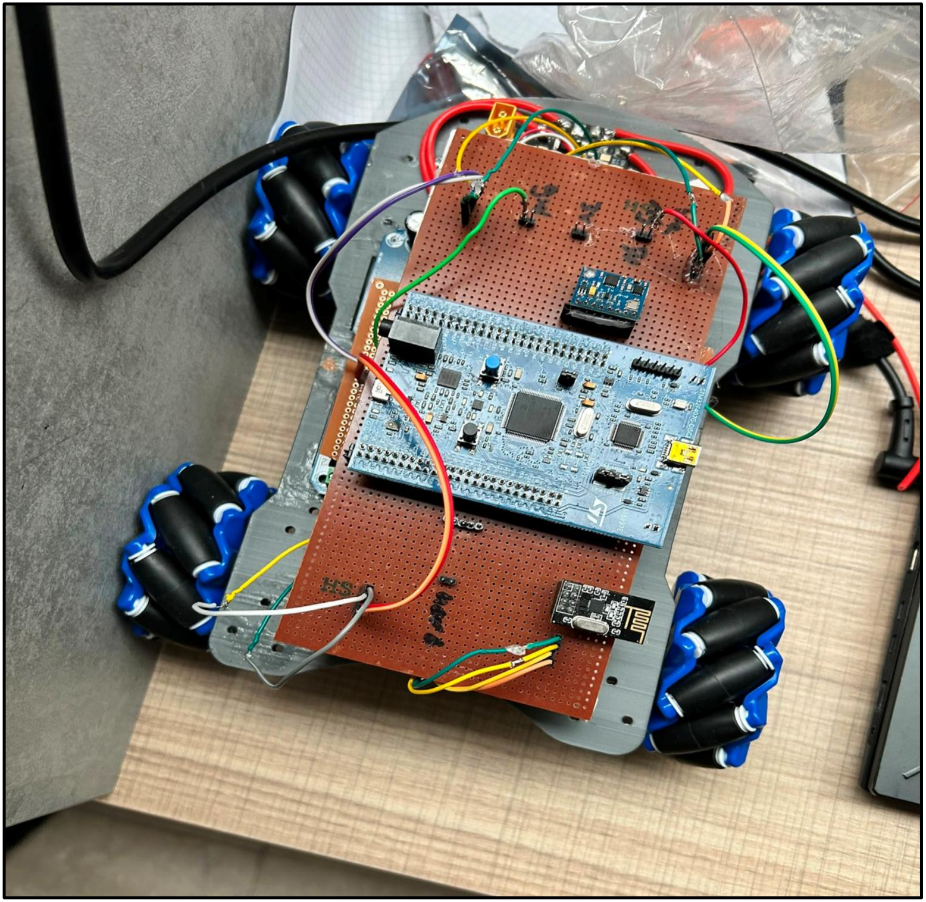
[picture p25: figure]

EK 1. Otonom aracın fiziksel görünümü. Holonomik sürüş için dört adet mecanum tekerlek,

alçak seviye hareket kontrolünü sağlayan STM32F4 Discovery kartı, motor sürücü ve güç

dağıtımı için delikli pertinaks üzerine kurulan devreler ve nRF24L01+ 2.4 GHz kablosuz

haberleşme modülü görülmektedir

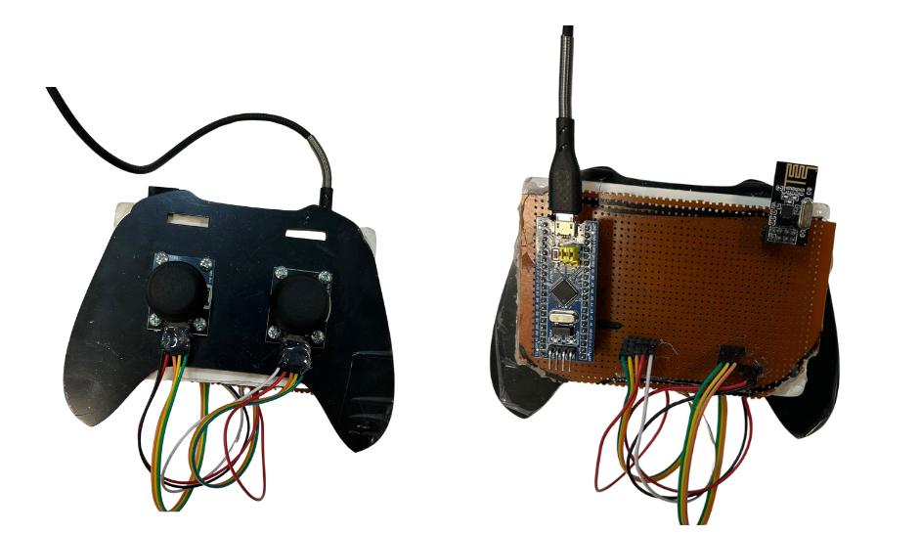
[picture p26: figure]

EK 2. Aracı 2.4 GHz üzerinden kablosuz yöneten el kumandası. Solda kumandanın ön yüzü

(iki analog joystick), sağda arka yüzü görülmektedir. Delikli pertinaks üzerine yerleştirilen

STM32 (Blue Pill) kartı joystick verilerini okuyarak nRF24L01+ modülü aracılığıyla araca

iletmektedir.

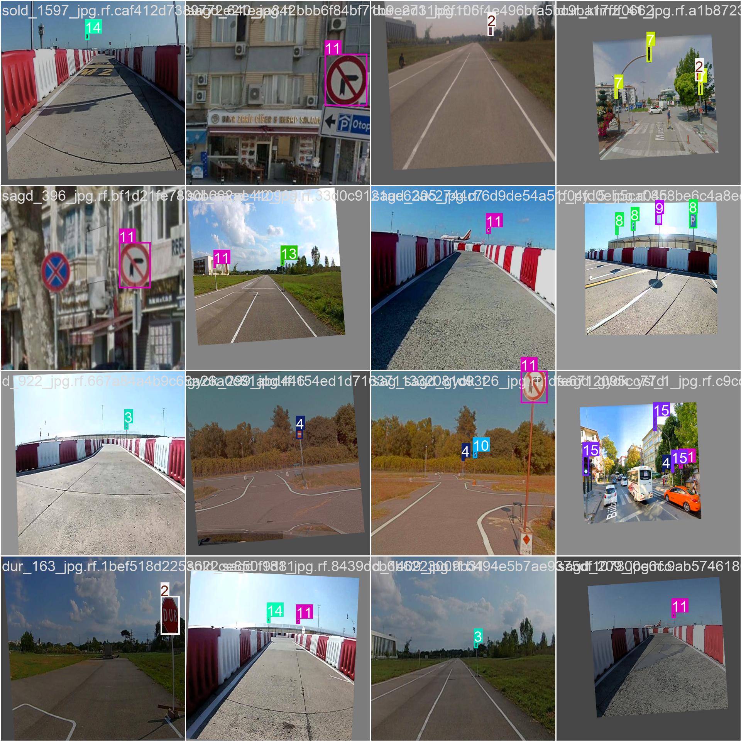
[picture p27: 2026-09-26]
project_codes/python_pc_folder/Yolo_training_reslut/train_batch111581.jpg

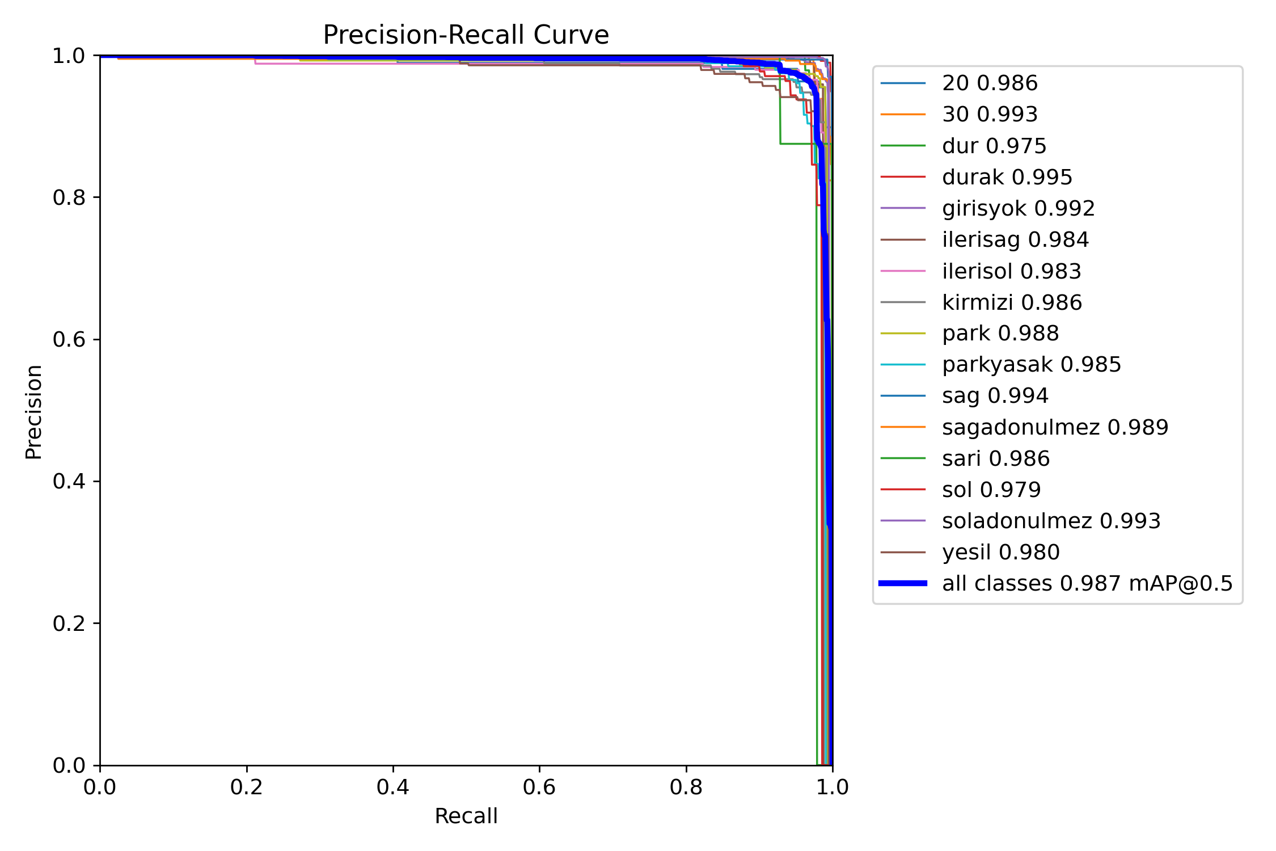
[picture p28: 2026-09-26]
project_codes/python_pc_folder/Yolo_training_reslut/BoxPR_curve.png

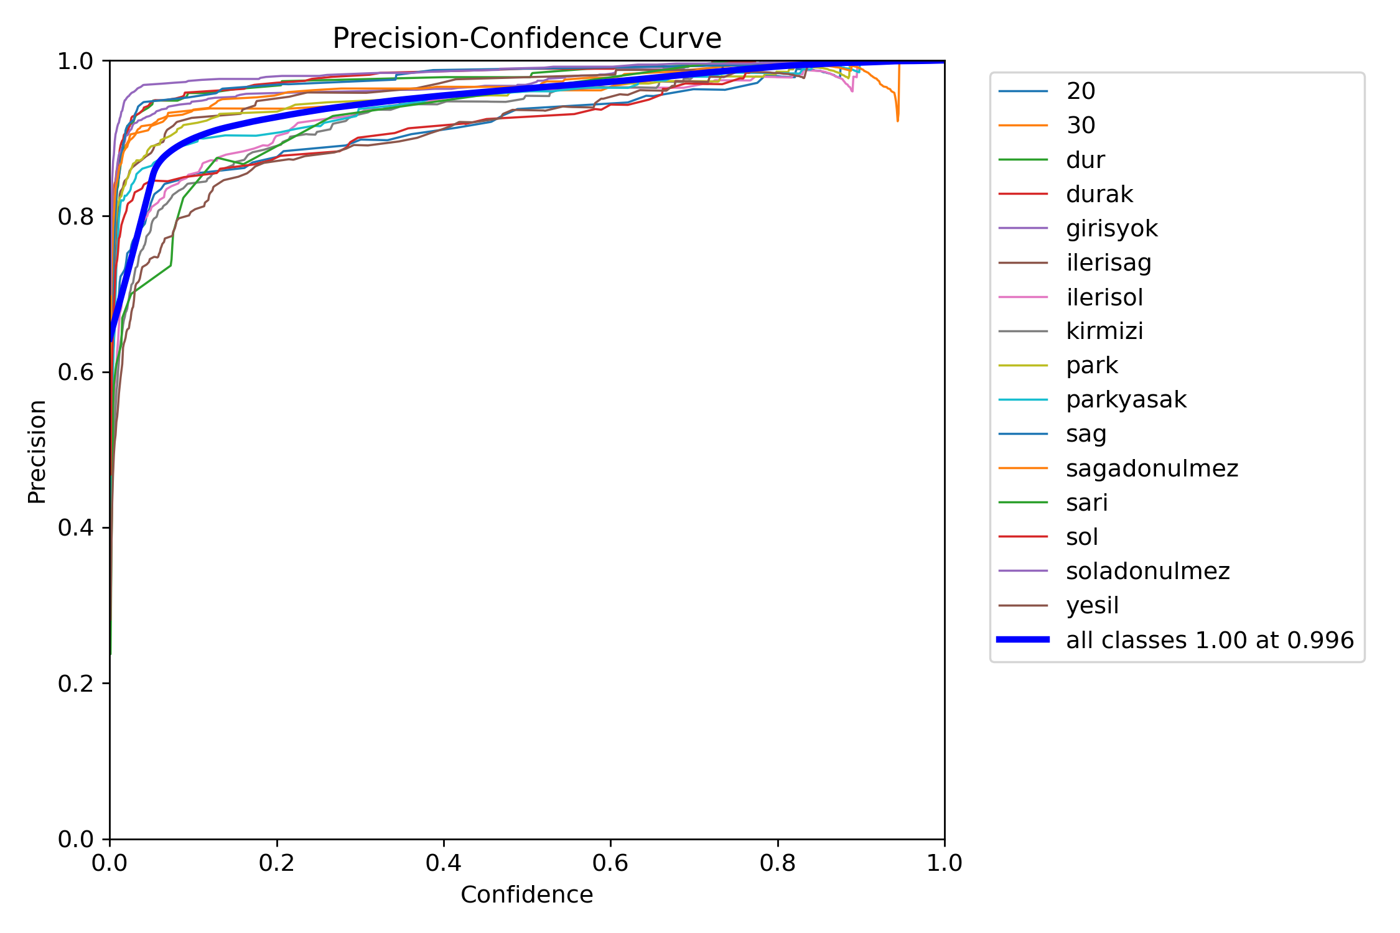
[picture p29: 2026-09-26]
project_codes/python_pc_folder/Yolo_training_reslut/BoxP_curve.png

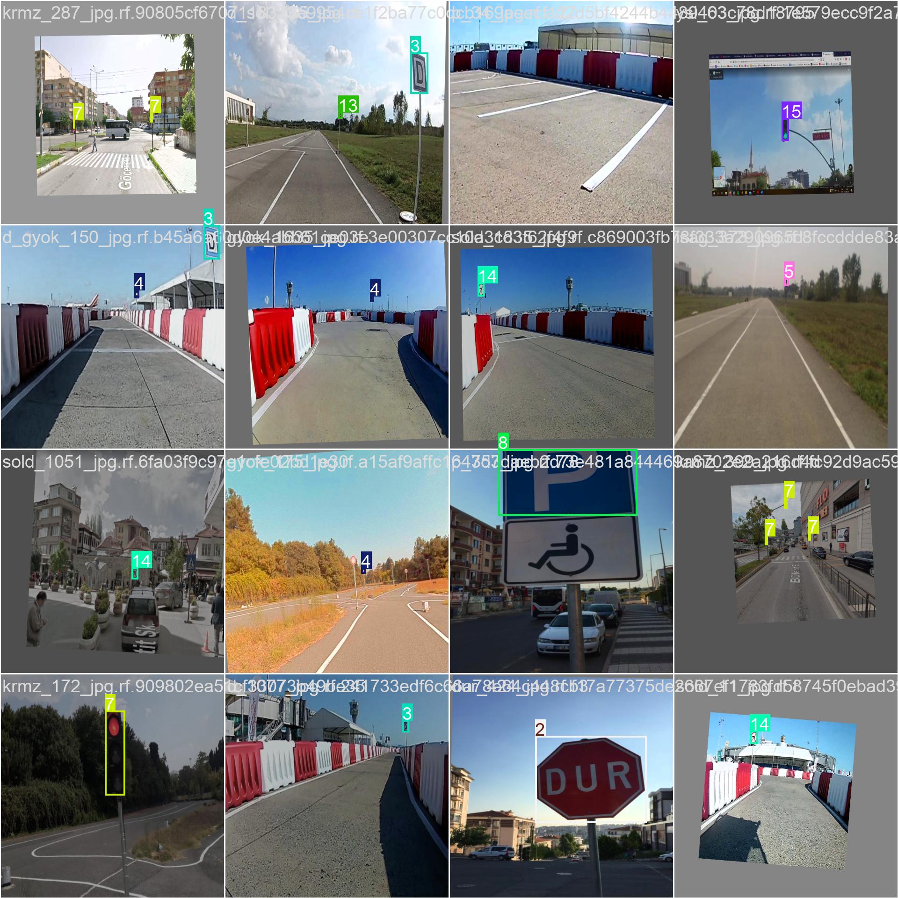
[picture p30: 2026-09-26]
project_codes/python_pc_folder/Yolo_training_reslut/train_batch111580.jpg

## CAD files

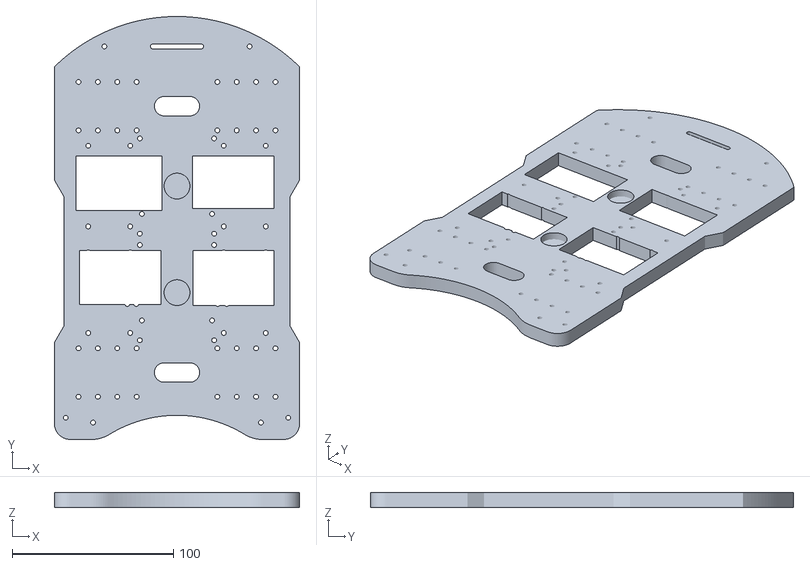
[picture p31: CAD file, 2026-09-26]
3d_parts/şase.stl
152.0 x 262.0 x 9.00

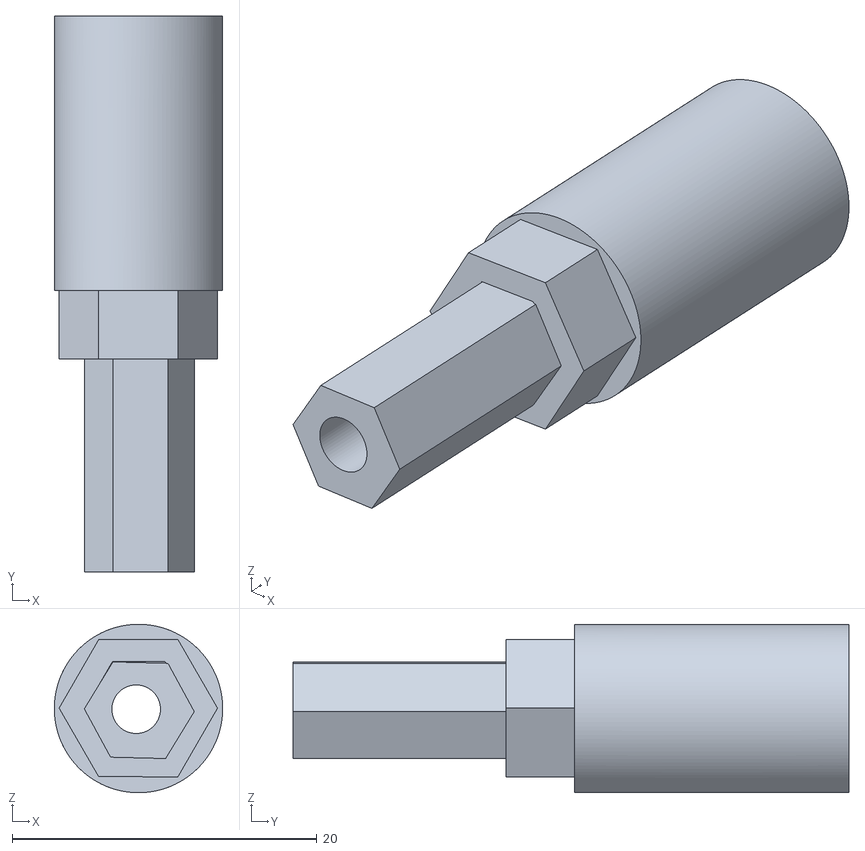
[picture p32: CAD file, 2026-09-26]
3d_parts/Component1.stl
11.0 x 36.5 x 11.0

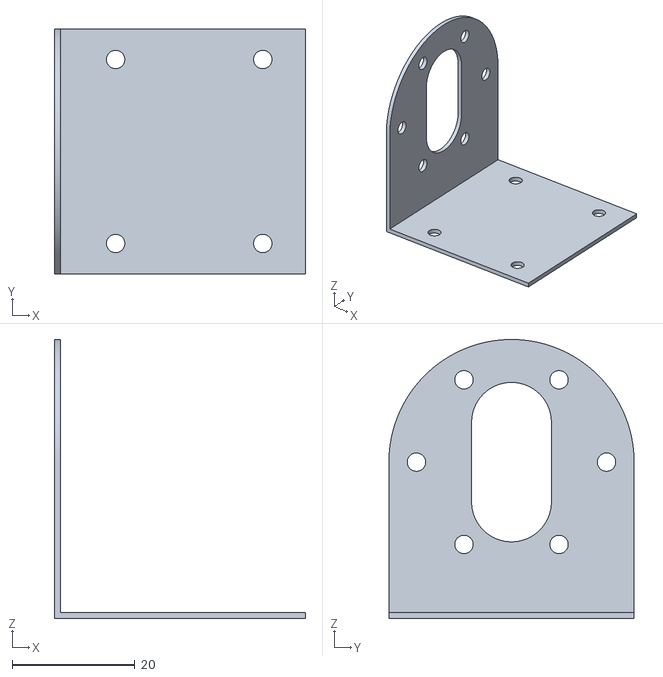
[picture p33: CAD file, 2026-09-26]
3d_parts/Motor Bracket.stl
41.0 x 40.0 x 45.5

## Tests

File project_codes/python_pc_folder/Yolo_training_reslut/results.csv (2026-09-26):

epoch | time | train/box_loss | train/cls_loss | train/dfl_loss | metrics/precision(B) | metrics/recall(B) | metrics/mAP50(B) | metrics/mAP50-95(B) | val/box_loss | val/cls_loss | val/dfl_loss | lr/pg0 | lr/pg1 | lr/pg2
1 | 231.239 | 1.07987 | 1.48369 | 0.99417 | 0.82368 | 0.74067 | 0.80327 | 0.54781 | 1.04758 | 0.84806 | 0.96292 | 0.000199749 | 0.000199749 | 0.0802248
2 | 457.716 | 1.0573 | 0.90072 | 1.00345 | 0.84366 | 0.79014 | 0.85146 | 0.565 | 1.11443 | 0.77658 | 0.99992 | 0.000397111 | 0.000397111 | 0.0604222
3 | 683.918 | 1.04807 | 0.84438 | 1.01406 | 0.87937 | 0.81803 | 0.90568 | 0.58789 | 1.12813 | 0.70482 | 0.99371 | 0.000591832 | 0.000591832 | 0.0406169
4 | 907.467 | 1.03382 | 0.78281 | 0.99385 | 0.87006 | 0.7759 | 0.89766 | 0.58836 | 1.0909 | 0.85055 | 0.97895 | 0.000783914 | 0.000783914 | 0.020809
5 | 1126.72 | 1.00733 | 0.74403 | 0.98878 | 0.88361 | 0.88245 | 0.93637 | 0.61861 | 1.09027 | 0.6282 | 0.97639 | 0.000973356 | 0.000973356 | 0.00099845
6 | 1350.25 | 0.99301 | 0.70325 | 0.98479 | 0.91843 | 0.90198 | 0.94835 | 0.65174 | 0.991 | 0.57161 | 0.9558 | 0.000967 | 0.000967 | 0.000967
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

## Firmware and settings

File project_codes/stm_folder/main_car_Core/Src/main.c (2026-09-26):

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
/* Includes ------------------------------------------------------------------*/
#include "main.h"

/* USER CODE BEGIN Includes */
#include <string.h>
#include <stdio.h>
#include <stdlib.h>
#include <stdarg.h>
#include <math.h>
#include <mpu6050.h>
#include "motor.h"
#include "NRF24.h"
#include "NRF24_reg_addresses.h"
#include "NRF24_conf.h"
/* USER CODE END Includes */

/* USER CODE BEGIN PTD */
typedef struct __attribute__((packed)) {
    uint16_t header;          // 0xAA55
    int16_t vx;
    int16_t vy;
    int16_t wz;
    float target_yaw_deg;     // NEW: yaw setpoint from Pi
    uint8_t mode;             // 0 manual, 1 auto
    uint8_t checksum;
} PiCommandFrame;

typedef struct __attribute__((packed)) {
    uint16_t header;      // 0x55AA

    float rpm_FL;
    float rpm_FR;
    float rpm_RL;
    float rpm_RR;

    float yaw_angle;
    float gyro_z_dps;

    float ultra_left_cm;    // USART1
    float ultra_right_cm;   // USART3
    float ultra_front_cm;   // UART4

    float accel_x;
    float accel_y;
    float accel_z;

    float dt;
    float pid_hz;

    int16_t pwm_FL;
    int16_t pwm_FR;
    int16_t pwm_RL;
    int16_t pwm_RR;

    uint16_t change_value;

    uint8_t imu_ok;
    uint8_t status;

    uint8_t checksum;
} StmTelemetryFrame;

/* USER CODE END PTD */

/* USER CODE BEGIN PD */

float yaw_rate_measured = 0.0f;
float target_yaw = 0.0f;
float yaw_correction = 0.0f;

#define YAW_LIMIT_DEG        3.0f

// Rotate mode
#define ROT_YAW_KP           80.0f
#define ROT_YAW_KD           0.0f
#define ROT_YAW_BASE_PWM     2000.0f
#define ROT_YAW_CORR_MAX     5000.0f

// Drive straight mode
#define DRIVE_YAW_KP           70.0f
#define DRIVE_YAW_KD           0.0f
#define DRIVE_YAW_BASE_PWM     1500.0f
#define DRIVE_YAW_CORR_MAX     5000.0f

// Modes
#define MODE_ROTATE_YAW      1
#define MODE_DRIVE_HEADING   2

#define JOY_MIN        0
#define JOY_MAX        4050

#define JOY_CENTER     1975
#define JOY_DEADZONE   75

#define JOY_CENTER_LOW   (JOY_CENTER - JOY_DEADZONE)   // 1900
#define JOY_CENTER_HIGH  (JOY_CENTER + JOY_DEADZONE)   // 2050
#define PWM_MAX  8399
/* USER CODE END PD */

I2C_HandleTypeDef hi2c1;
DMA_HandleTypeDef hdma_i2c1_rx;

SPI_HandleTypeDef hspi1;

TIM_HandleTypeDef htim1;
TIM_HandleTypeDef htim2;
TIM_HandleTypeDef htim3;
TIM_HandleTypeDef htim4;
TIM_HandleTypeDef htim5;
TIM_HandleTypeDef htim6;
TIM_HandleTypeDef htim8;

UART_HandleTypeDef huart4;
UART_HandleTypeDef huart1;
UART_HandleTypeDef huart2;
UART_HandleTypeDef huart3;
DMA_HandleTypeDef hdma_usart2_rx;
DMA_HandleTypeDef hdma_usart2_tx;

/* USER CODE BEGIN PV */

volatile uint8_t imu_recovery_request = 0;
volatile uint32_t imu_last_recovery_try = 0;
volatile uint32_t imu_last_data_tick = 0;   // updated whenever fresh IMU data arrives
uint8_t ultra1_cmd = 0x01;
uint8_t ultra3_cmd = 0x01;
uint8_t ultra4_cmd = 0x01;

uint8_t ultra1_rx_buf[3];
uint8_t ultra3_rx_buf[3];
uint8_t ultra4_rx_buf[3];

volatile uint8_t ultra1_ready = 0;
volatile uint8_t ultra3_ready = 0;
volatile uint8_t ultra4_ready = 0;

uint16_t ultra1_distance_mm = 0;
uint16_t ultra3_distance_mm = 0;
uint16_t ultra4_distance_mm = 0;

float ultra1_distance_cm = 0.0f;
float ultra3_distance_cm = 0.0f;
float ultra4_distance_cm = 0.0f;

    int32_t flR ;
    int32_t frR ;
    int32_t rlR ;
    int32_t rrR ;

int32_t fl;
int32_t fr ;
int32_t rl ;
int32_t rr;



PiCommandFrame pi_cmd;
StmTelemetryFrame stm_tel;

volatile uint8_t uart_rx_ready = 0;
volatile uint8_t uart_tx_complete = 1;

uint8_t rx_buffer[sizeof(PiCommandFrame)];

float gyro_z_bias = 0.0f;   // measured at startup
/////////////////////////////////NRF////////////////////////
#define PLD_S 12
#define TX_DS   5   // Transmit Data Sent
#define MAX_RT  4   // Maximum Retransmits
uint8_t rx_ack_pld[PLD_S] = {"OK"};
uint8_t tx_addr[5] = {0x45, 0x55, 0x67, 0x10, 0x21};


uint16_t counter =0 ;
uint16_t data = 0;
uint8_t dataR[PLD_S];
uint8_t dataT[PLD_S];
volatile uint8_t irq = 0;
uint16_t dataa = 0;


float gyro_z_p;
float gyro_z_d;
float yaw_angle = 0.0f;
/* ── IMU / Yaw filtering (from drone code) ── */
float gyro_z_p_state = 0.0f;   // light filter → P and I
float gyro_z_d_state = 0.0f;   // heavy filter → D



#define RPM_SAMPLE_TICKS  10   // compute RPM every 10 ticks → ~20ms window

static int32_t acc_FL = 0, acc_FR = 0, acc_RL = 0, acc_RR = 0;
static uint8_t rpm_tick_count = 0;
static float   acc_dt = 0.0f;


int16_t motor_pwm;
//........................................MOTORS...................................................
uint8_t imu_ok = 0;

Motor_t motor_FL;
Motor_t motor_FR;
Motor_t motor_RL;
Motor_t motor_RR;

#define ENC_COUNTS_PER_REV   1320.0f    // ← CHANGE TO YOUR REAL VALUE
//..............................imu config ..........................
uint8_t mpu_raw_data[14];
volatile uint8_t mpu_data_ready = 0;
MPU6050_Data mpuData;
volatile uint8_t nrf_data_ready = 0;
//.................................. timer calculations .......................
static uint32_t  dwt_last = 0;
static float     dt       = 0.000f;     // seconds
static float     pid_hz   = 0.0f;       // what you want to monitor

uint16_t receivedY;
uint16_t receivedX;
uint16_t servo_pwma2;
uint16_t receivedYa;
uint16_t receivedXa;
uint16_t change;
uint16_t change2;

int16_t pwm_FL, pwm_FR, pwm_RL, pwm_RR;
//.....................................

/* USER CODE END PV */

void SystemClock_Config(void);
static void MX_GPIO_Init(void);
static void MX_DMA_Init(void);
static void MX_I2C1_Init(void);
static void MX_TIM2_Init(void);
static void MX_TIM3_Init(void);
static void MX_TIM4_Init(void);
static void MX_TIM5_Init(void);
static void MX_TIM6_Init(void);
static void MX_TIM8_Init(void);
static void MX_TIM1_Init(void);
static void MX_SPI1_Init(void);
static void MX_USART2_UART_Init(void);
static void MX_UART4_Init(void);
static void MX_USART1_UART_Init(void);
static void MX_USART3_UART_Init(void);
/* USER CODE BEGIN PFP */
uint8_t calc_checksum(uint8_t *data, uint16_t len);
void process_pi_command(void);
void send_telemetry_to_pi(void);
/* USER CODE END PFP */

/* USER CODE BEGIN 0 */
uint8_t calc_checksum(uint8_t *data, uint16_t len)
{
    uint8_t sum = 0;
    for(uint16_t i = 0; i < len - 1; i++)
        sum += data[i];
    return sum;
}

float wrap_angle(float a)
{
    while (a > 180.0f) a -= 360.0f;
    while (a < -180.0f) a += 360.0f;
    return a;
}

#define I2C1_SCL_PORT   GPIOB
#define I2C1_SCL_PIN    GPIO_PIN_6      // <-- verify against MspInit
#define I2C1_SDA_PORT   GPIOB
#define I2C1_SDA_PIN    GPIO_PIN_7      // <-- verify against MspInit

static void i2c_short_delay(void)
{
    for (volatile int i = 0; i < 800; i++) __NOP();
}

void I2C1_BusRecovery(void)
{
    GPIO_InitTypeDef gpio = {0};
    __HAL_RCC_GPIOB_CLK_ENABLE();

    HAL_I2C_DeInit(&hi2c1);

    gpio.Mode  = GPIO_MODE_OUTPUT_OD;
    gpio.Pull  = GPIO_PULLUP;
    gpio.Speed = GPIO_SPEED_FREQ_LOW;
    gpio.Pin = I2C1_SCL_PIN; HAL_GPIO_Init(I2C1_SCL_PORT, &gpio);
    gpio.Pin = I2C1_SDA_PIN; HAL_GPIO_Init(I2C1_SDA_PORT, &gpio);

    HAL_GPIO_WritePin(I2C1_SCL_PORT, I2C1_SCL_PIN, GPIO_PIN_SET);
    HAL_GPIO_WritePin(I2C1_SDA_PORT, I2C1_SDA_PIN, GPIO_PIN_SET);
    i2c_short_delay();

    for (int i = 0; i < 9; i++)
    {
        if (HAL_GPIO_ReadPin(I2C1_SDA_PORT, I2C1_SDA_PIN) == GPIO_PIN_SET) break;
        HAL_GPIO_WritePin(I2C1_SCL_PORT, I2C1_SCL_PIN, GPIO_PIN_RESET); i2c_short_delay();
        HAL_GPIO_WritePin(I2C1_SCL_PORT, I2C1_SCL_PIN, GPIO_PIN_SET);   i2c_short_delay();
    }

    HAL_GPIO_WritePin(I2C1_SDA_PORT, I2C1_SDA_PIN, GPIO_PIN_RESET); i2c_short_delay();
    HAL_GPIO_WritePin(I2C1_SCL_PORT, I2C1_SCL_PIN, GPIO_PIN_SET);   i2c_short_delay();
    HAL_GPIO_WritePin(I2C1_SDA_PORT, I2C1_SDA_PIN, GPIO_PIN_SET);   i2c_short_delay();

    MX_I2C1_Init();
}


void calibrate_gyro_bias(void)
{
    if (!imu_ok) return;

    const int   SAMPLES  = 1000;
    const float DELAY_MS = 2.0f;   // ms between samples
    float sum = 0.0f;

    for (int i = 0; i < SAMPLES; i++)
    {
        /* wait for a fresh DMA result */
        mpu_data_ready = 0;
        MPU6050_Start_Read_All_DMA(&hi2c1, mpu_raw_data);
        uint32_t t = HAL_GetTick();
        while (!mpu_data_ready && (HAL_GetTick() - t) < 50);   // 50 ms timeout

        if (mpu_data_ready)
        {
            mpu_data_ready = 0;
            MPU6050_Process_Data(&mpuData, mpu_raw_data);
            sum += mpuData.gyro_z_dps;
        }
        HAL_Delay((uint32_t)DELAY_MS);
    }

    gyro_z_bias = sum / (float)SAMPLES;
}

float pt1_filter(float input, float cutoff, float dt, float *state)
{
    float rc = 1.0f / (2.0f * M_PI * cutoff);
    float alpha = dt / (dt + rc);
    *state = *state + alpha * (input - *state);
    return *state;
}


int _write(int32_t file, uint8_t *ptr, int32_t len)
{
    int i=0;
    for(i=0 ; i<len ; i++)
        ITM_SendChar((*ptr++));  // Send each character over SWO
    return len;
}

static int16_t joy_map(uint16_t raw, int16_t max_out)
{
    if (raw >= JOY_CENTER_LOW && raw <= JOY_CENTER_HIGH)
        return 0;

    if (raw > JOY_CENTER_HIGH)
        return (int16_t)(
            ((int32_t)(raw - JOY_CENTER_HIGH) * max_out)
            / (JOY_MAX - JOY_CENTER_HIGH)
        );
    else
        return (int16_t)(
            -((int32_t)(JOY_CENTER_LOW - raw) * max_out)
            / (JOY_CENTER_LOW - JOY_MIN)
        );
}


void read_imu()
{
    // this function is connected to timer6
    if(!imu_ok) return;

    if (HAL_I2C_GetState(&hi2c1) == HAL_I2C_STATE_READY && !mpu_data_ready)
    {
        if (MPU6050_Start_Read_All_DMA(&hi2c1, mpu_raw_data) != HAL_OK)
        {
            imu_ok = 0;
            yaw_correction = 0.0f;
            mpu_data_ready = 0;
            imu_recovery_request = 1;

            HAL_GPIO_WritePin(LEDB_GPIO_Port, LEDB_Pin, GPIO_PIN_SET); // IMU problem

            return;
        }
    }

    if (!mpu_data_ready) return;

    mpu_data_ready = 0;

    MPU6050_Process_Data(&mpuData, mpu_raw_data);
    imu_last_data_tick = HAL_GetTick();

    float gz_corrected = mpuData.gyro_z_dps - gyro_z_bias;

    gyro_z_p = pt1_filter(gz_corrected, 100.0f, dt, &gyro_z_p_state);
    gyro_z_d = pt1_filter(gz_corrected,  30.0f, dt, &gyro_z_d_state);

    yaw_angle += gyro_z_p * dt;
    yaw_angle = wrap_angle(yaw_angle);

    float yaw_error = wrap_angle(target_yaw - yaw_angle);

    if (fabsf(yaw_error) <= YAW_LIMIT_DEG)
    {
        yaw_correction = 0.0f;
    }
    else
    {
        if (pi_cmd.mode == MODE_ROTATE_YAW)
        {
            float sign = (yaw_error > 0.0f) ? 1.0f : -1.0f;

            yaw_correction =
                (sign * ROT_YAW_BASE_PWM)
                + (ROT_YAW_KP * yaw_error)
                - (ROT_YAW_KD * gyro_z_d);

            if (yaw_correction > ROT_YAW_CORR_MAX)
                yaw_correction = ROT_YAW_CORR_MAX;

            if (yaw_correction < -ROT_YAW_CORR_MAX)
                yaw_correction = -ROT_YAW_CORR_MAX;
        }
        else if (pi_cmd.mode == MODE_DRIVE_HEADING)
        {
            float sign = (yaw_error > 0.0f) ? 1.0f : -1.0f;

            yaw_correction =
                (sign * DRIVE_YAW_BASE_PWM)
                + (DRIVE_YAW_KP * yaw_error)
                - (DRIVE_YAW_KD * gyro_z_d);

            if (yaw_correction > DRIVE_YAW_CORR_MAX)
                yaw_correction = DRIVE_YAW_CORR_MAX;

            if (yaw_correction < -DRIVE_YAW_CORR_MAX)
                yaw_correction = -DRIVE_YAW_CORR_MAX;
        }
        else
        {
            yaw_correction = 0.0f;
        }
    }
}

void timerfuncion(){
	// this funciton is connected to timer6 thats why its not showen that its called
	static uint8_t divider = 0;

	    if(++divider & 1) return;

	    if(divider < 2) return;   // skip one interrupt

	    divider = 0;
	//................................DT Calculations.......................................
	    uint32_t dwt_now = DWT->CYCCNT;
	    	 			  uint32_t cycles_elapsed = dwt_now - dwt_last;
	    	 			  dwt_last = dwt_now;
	    	 			  if (cycles_elapsed == 0) cycles_elapsed = 1;
	    	 			  dt = (float)cycles_elapsed / (float)SystemCoreClock;
	    	 			  pid_hz = 1.0f / dt;

	    	 			 Motor_UpdateEncoder(&motor_FL);
	    	 			 Motor_UpdateEncoder(&motor_FR);
	    	 			 Motor_UpdateEncoder(&motor_RL);
	    	 			 Motor_UpdateEncoder(&motor_RR);

	    	 			 // Accumulate counts and time
	    	 			 acc_FL += motor_FL.delta_encoder;
	    	 			 acc_FR += motor_FR.delta_encoder;
	    	 			 acc_RL += motor_RL.delta_encoder;
	    	 			 acc_RR += motor_RR.delta_encoder;
	    	 			 acc_dt += dt;
	    	 			 rpm_tick_count++;

	    	 			 if (rpm_tick_count >= RPM_SAMPLE_TICKS)
	    	 			 {
	    	 			     // Temporarily swap in accumulated values for RPM calc
	    	 			     motor_FL.delta_encoder = acc_FL;
	    	 			     motor_FR.delta_encoder = acc_FR;
	    	 			     motor_RL.delta_encoder = acc_RL;
	    	 			     motor_RR.delta_encoder = acc_RR;

	    	 			     Motor_ComputeRPM(&motor_FL, acc_dt);
	    	 			     Motor_ComputeRPM(&motor_FR, acc_dt);
	    	 			     Motor_ComputeRPM(&motor_RL, acc_dt);
	    	 			     Motor_ComputeRPM(&motor_RR, acc_dt);

	    	 			     // Reset accumulators
	    	 			     acc_FL = acc_FR = acc_RL = acc_RR = 0;
	    	 			     acc_dt = 0.0f;
	    	 			     rpm_tick_count = 0;
	    	 			 }




			        	  Motor_SetPWM(&motor_FL, pwm_FL/2);
			        	  Motor_SetPWM(&motor_FR, pwm_FR/2);
			        	  Motor_SetPWM(&motor_RL, pwm_RL/2);
			        	  Motor_SetPWM(&motor_RR, pwm_RR/2);
}



void decode_received_data(void)
{
	dataa      = nrf24_uint8_t_to_type(dataR, sizeof(dataR));
	    receivedY  = ((uint16_t)dataR[1] << 8) | dataR[2];
	    receivedX  = ((uint16_t)dataR[3] << 8) | dataR[4];
	    receivedYa = ((uint16_t)dataR[5] << 8) | dataR[6];
	    receivedXa = ((uint16_t)dataR[7] << 8) | dataR[8];
	    change     = dataR[10];
	    change2    = dataR[11];

	    int16_t throttle = joy_map(receivedYa, PWM_MAX);  // forward / back
	    int16_t strafe   = joy_map(receivedXa,  PWM_MAX);  // right / left
	    int16_t yaw      = joy_map(receivedY, PWM_MAX);  // yaw right / left

	     fl = (int32_t)throttle + strafe + yaw;
	     fr = (int32_t)throttle - strafe - yaw;
	     rl = (int32_t)throttle - strafe + yaw;
	     rr = (int32_t)throttle + strafe - yaw;

	     if(change==1){
	    fl -= yaw_correction;
	    fr += yaw_correction;
	    rl -= yaw_correction;
	    rr += yaw_correction;
	     }

	    int32_t peak = fl;
	    if (abs(fr) > abs(peak)) peak = fr;
	    if (abs(rl) > abs(peak)) peak = rl;
	    if (abs(rr) > abs(peak)) peak = rr;

	    if (abs(peak) > PWM_MAX) {
	        fl = fl * PWM_MAX / abs(peak);
	        fr = fr * PWM_MAX / abs(peak);
	        rl = rl * PWM_MAX / abs(peak);
	        rr = rr * PWM_MAX / abs(peak);
	    }

	    if(change == 0)
	    {
	        pwm_FL = (int16_t)fl;
	        pwm_FR = (int16_t)fr;
	        pwm_RL = (int16_t)rl;
	        pwm_RR = (int16_t)rr;
	    }
}

void reciver(void)
{
    nrf24_listen();
    nrf24_en_ack_pld(enable);
    nrf24_en_dyn_ack(disable);
}

void handle_irq(void)
{
	if (irq == 1) {
	        uint8_t stat = nrf24_r_status();
	        if (stat & (1 << RX_DR)) {
	            counter = (counter + 1) % 21;
	            nrf24_receive(dataR, sizeof(dataR));
	            nrf24_transmit_rx_ack_pld(0, rx_ack_pld, sizeof(rx_ack_pld));
	            nrf_data_ready = 1;  // ← set flag here
	        }
        irq = 0;
    }
}

void conf(void)
{
    csn_high();
    ce_high();

    HAL_Delay(5);

    ce_low();

    nrf24_init();

    nrf24_listen();

    nrf24_auto_ack_all(auto_ack);
    nrf24_en_ack_pld(disable);
    nrf24_dpl(disable);

    nrf24_set_crc(no_crc, _1byte);

    nrf24_tx_pwr(_0dbm);
    nrf24_data_rate(_250kbps);
    nrf24_set_channel(83);
    nrf24_set_addr_width(5);

    nrf24_set_rx_dpl(0, disable);
    nrf24_set_rx_dpl(1, disable);
    nrf24_set_rx_dpl(2, disable);
    nrf24_set_rx_dpl(3, disable);
    nrf24_set_rx_dpl(4, disable);
    nrf24_set_rx_dpl(5, disable);

    nrf24_pipe_pld_size(0, PLD_S);

    nrf24_auto_retr_delay(4);
    nrf24_auto_retr_limit(10);

    nrf24_open_tx_pipe(tx_addr);
    nrf24_open_rx_pipe(0, tx_addr);

    ce_high();
}


/* USER CODE END 0 */

/**
  * @brief  The application entry point.
  * @retval int
  */
int main(void)
{

  /* MCU Configuration--------------------------------------------------------*/

  /* Reset of all peripherals, Initializes the Flash interface and the Systick. */
  HAL_Init();

  /* Configure the system clock */
  SystemClock_Config();

  /* Initialize all configured peripherals */
  MX_GPIO_Init();
  MX_DMA_Init();
  MX_I2C1_Init();
  MX_TIM2_Init();
  MX_TIM3_Init();
  MX_TIM4_Init();
  MX_TIM5_Init();
  MX_TIM6_Init();
  MX_TIM8_Init();
  MX_TIM1_Init();
  MX_SPI1_Init();
  MX_USART2_UART_Init();
  MX_UART4_Init();
  MX_USART1_UART_Init();
  MX_USART3_UART_Init();
  /* USER CODE BEGIN 2 */
  conf();

  I2C1_BusRecovery();

  if (MPU6050_Init(&hi2c1, ACCEL_RANGE_8G, GYRO_RANGE_500) != 0)
  {
	  HAL_GPIO_WritePin(LEDB_GPIO_Port, LEDB_Pin, GPIO_PIN_SET);
      imu_ok = 0;
      imu_recovery_request = 1;
  }
  else
  {
	  HAL_GPIO_WritePin(LEDB_GPIO_Port, LEDB_Pin, GPIO_PIN_RESET);
      imu_ok = 1;
      imu_last_data_tick = HAL_GetTick();
  }

     	  /*HAL_GPIO_WritePin(LEDB_GPIO_Port, LEDB_Pin, GPIO_PIN_SET);
     	  HAL_GPIO_WritePin(LEDG_GPIO_Port, LEDG_Pin, GPIO_PIN_RESET);*/

     	  printf("main");

     	 mpuData.accel_range = ACCEL_RANGE_8G;
     	 mpuData.gyro_range  = GYRO_RANGE_500;
     	 HAL_Delay(5000);
//...................................... DT calculations.................................
  CoreDebug->DEMCR |= CoreDebug_DEMCR_TRCENA_Msk;
  DWT->CYCCNT = 0;
  DWT->CTRL |= DWT_CTRL_CYCCNTENA_Msk;

  dwt_last = DWT->CYCCNT;

	 //...............................................TIMERS........................................
	 HAL_TIM_Encoder_Start(&htim2, TIM_CHANNEL_ALL);
	 HAL_TIM_Encoder_Start(&htim3, TIM_CHANNEL_ALL);
	 HAL_TIM_Encoder_Start(&htim4, TIM_CHANNEL_ALL);
	 HAL_TIM_Encoder_Start(&htim5, TIM_CHANNEL_ALL);


	 HAL_TIM_PWM_Start(&htim1, TIM_CHANNEL_1);
	 HAL_TIM_PWM_Start(&htim1, TIM_CHANNEL_2);
	 HAL_TIM_PWM_Start(&htim1, TIM_CHANNEL_3);
	 HAL_TIM_PWM_Start(&htim1, TIM_CHANNEL_4);


	 HAL_TIM_PWM_Start(&htim8, TIM_CHANNEL_1);
	 HAL_TIM_PWM_Start(&htim8, TIM_CHANNEL_2);
	 HAL_TIM_PWM_Start(&htim8, TIM_CHANNEL_3);
	 HAL_TIM_PWM_Start(&htim8, TIM_CHANNEL_4);


	 HAL_TIM_Base_Start_IT(&htim6);

	 Motor_Init(&motor_FL, &htim1, TIM_CHANNEL_1, TIM_CHANNEL_2, &htim2, ENC_COUNTS_PER_REV);
	 Motor_Init(&motor_FR, &htim1, TIM_CHANNEL_3, TIM_CHANNEL_4, &htim3, ENC_COUNTS_PER_REV);
	 Motor_Init(&motor_RL, &htim8, TIM_CHANNEL_1, TIM_CHANNEL_2, &htim4, ENC_COUNTS_PER_REV);
	 Motor_Init(&motor_RR, &htim8, TIM_CHANNEL_3, TIM_CHANNEL_4, &htim5, ENC_COUNTS_PER_REV);

	 Motor_Start(&motor_FL);
	 Motor_Start(&motor_FR);
	 Motor_Start(&motor_RL);
	 Motor_Start(&motor_RR);



	 calibrate_gyro_bias();
	 imu_last_data_tick = HAL_GetTick();

	 HAL_UART_Receive_DMA(&huart2, rx_buffer, sizeof(PiCommandFrame));
	 HAL_UART_Receive_IT(&huart1, ultra1_rx_buf, 3);
	 HAL_UART_Receive_IT(&huart3, ultra3_rx_buf, 3);
	 HAL_UART_Receive_IT(&huart4, ultra4_rx_buf, 3);


  /* USER CODE END 2 */

  /* Infinite loop */
  /* USER CODE BEGIN WHILE */
  while (1)
  {

	  if (imu_recovery_request || (imu_ok && (HAL_GetTick() - imu_last_data_tick > 200)))
		  {
		      /* rate-limit attempts so the loop stays responsive when the IMU is absent */
		  if (imu_ok && (HAL_GetTick() - imu_last_data_tick > 200))
		      {
		          imu_ok = 0;
		          yaw_correction = 0.0f;
		          HAL_GPIO_WritePin(LEDB_GPIO_Port, LEDB_Pin, GPIO_PIN_SET); // blue LED ON
		          imu_recovery_request = 1;
		      }

		      if (HAL_GetTick() - imu_last_recovery_try > 500)
		      {
		          imu_last_recovery_try = HAL_GetTick();
		          imu_recovery_request  = 0;

		          if (hi2c1.hdmarx != NULL) HAL_DMA_Abort(hi2c1.hdmarx);
		          if (hi2c1.hdmatx != NULL) HAL_DMA_Abort(hi2c1.hdmatx);

		          I2C1_BusRecovery();

		          if (HAL_I2C_IsDeviceReady(&hi2c1, (0x68 << 1), 2, 5) == HAL_OK &&
		              MPU6050_Init(&hi2c1, ACCEL_RANGE_8G, GYRO_RANGE_500) == 0)
		          {
		              imu_ok = 1;
		              yaw_angle = 0.0f;
		              yaw_correction = 0.0f;
		              gyro_z_p_state = 0.0f;
		              gyro_z_d_state = 0.0f;
		              imu_last_data_tick = HAL_GetTick();

		              HAL_GPIO_WritePin(LEDB_GPIO_Port, LEDB_Pin, GPIO_PIN_RESET); // OFF = OK
		          }
		          else
		          {
		              imu_ok = 0;
		              yaw_correction = 0.0f;

		              HAL_GPIO_WritePin(LEDB_GPIO_Port, LEDB_Pin, GPIO_PIN_SET); // ON = disconnected

		              // keep trying later
		              imu_recovery_request = 1;
		          }
		      }
		  }

	  handle_irq();
	  if (nrf_data_ready) {
	      nrf_data_ready = 0;
	      decode_received_data();
	  }

	  	  if (counter == 0) {
	  	      HAL_GPIO_WritePin(LEDR_GPIO_Port, LEDR_Pin, GPIO_PIN_SET);
	  	  } else {
	  	      HAL_GPIO_WritePin(LEDR_GPIO_Port, LEDR_Pin, GPIO_PIN_RESET);
	  	  }


	  	if(uart_rx_ready)
	  	    {
	  	        uart_rx_ready = 0;
	  	        process_pi_command();
	  	    }

	  	    static uint32_t last_uart_tx = 0;
	  	    if(HAL_GetTick() - last_uart_tx >= 20)
	  	    {
	  	        last_uart_tx = HAL_GetTick();
	  	        send_telemetry_to_pi();
	  	    }

	  	  static uint32_t last_ultra_request = 0;

	  	  if(HAL_GetTick() - last_ultra_request >= 100)
	  	  {
	  	      last_ultra_request = HAL_GetTick();

	  	      HAL_UART_Transmit(&huart1, &ultra1_cmd, 1, 10);
	  	      HAL_UART_Transmit(&huart3, &ultra3_cmd, 1, 10);
	  	      HAL_UART_Transmit(&huart4, &ultra4_cmd, 1, 10);
	  	  }

    /* USER CODE END WHILE */

    /* USER CODE BEGIN 3 */
  }
  /* USER CODE END 3 */
}

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
/* USER CODE BEGIN 4 */
void HAL_GPIO_EXTI_Callback(uint16_t GPIO_Pin)
{
	if(GPIO_Pin == GPIO_PIN_2){
			irq = 1;
		}
}
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

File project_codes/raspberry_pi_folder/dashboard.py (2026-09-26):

# dashboard.py
# ---------------------------------------------------------------------------
# Web interface (arayuz) for route_nav.
#
# Serves a single HTML page over HTTP that shows:
#   * a large live CAMERA feed (the debug overlay frame)
#   * a small live MASK feed
#   * a schematic MAP drawn as horizontal/vertical lines (auto-built from GRAPH)
#     showing the car, its current node, heading arrow, destination, the
#     predicted (planned) path, the next node and any blocked edges
#   * a control panel to type a START node, HEADING (N/E/S/W) and DESTINATION,
#     plus closed-road buttons (LEFT / RIGHT / FORWARD / CLEAR) and RESET
#   * a live telemetry readout
#
# Only the Python standard library + OpenCV (cv2) are used, so nothing extra
# needs to be installed on the Raspberry Pi.
#
# Public API used by route_nav:
#   dashboard.set_graph(GRAPH)          -> give it the map so it can lay it out
#   dashboard.set_control_callback(cb)  -> cb(dict) is called for each UI action
#   dashboard.start(port=8080)          -> start the server in a daemon thread
#   dashboard.push_frame(bgr_frame)     -> newest camera frame
#   dashboard.push_mask(mask_gray)      -> newest mask frame
#   dashboard.push_state(**fields)      -> newest navigation state (free-form)
# ---------------------------------------------------------------------------

import json
import threading
import time

import cv2

try:
    from http.server import BaseHTTPRequestHandler, ThreadingHTTPServer
except ImportError:  # very old Python fallback
    from http.server import BaseHTTPRequestHandler, HTTPServer
    from socketserver import ThreadingMixIn

    class ThreadingHTTPServer(ThreadingMixIn, HTTPServer):
        daemon_threads = True


JPEG_QUALITY = 70
STREAM_PERIOD = 0.04   # ~25 fps cap per video stream

# ---- shared state (written by route_nav, read by HTTP handlers) ----
_state_lock = threading.Lock()
_state = {}

_cam_lock = threading.Lock()
_cam_jpeg = None

_mask_lock = threading.Lock()
_mask_jpeg = None

_control_callback = None
_graph_layout = {"coords": {}, "edges": [], "nodes": []}

DIR_DELTA = {"NORTH": (0, -1), "SOUTH": (0, 1), "EAST": (1, 0), "WEST": (-1, 0)}


# ===========================================================================
# Public API
# ===========================================================================
def set_control_callback(cb):
    """Register a function cb(command_dict) called whenever the UI posts an
    action. It runs on the HTTP thread, so keep it light (route_nav just drops
    the dict into a queue and applies it on its own main thread)."""
    global _control_callback
    _control_callback = cb


def set_graph(graph):
    """Provide the navigation GRAPH so the map can be laid out automatically."""
    global _graph_layout
    _graph_layout = _compute_layout(graph)


def push_frame(frame):
    """Newest camera frame (BGR numpy array, as produced by OpenCV)."""
    global _cam_jpeg
    if frame is None:
        return
    ok, buf = cv2.imencode(".jpg", frame, [int(cv2.IMWRITE_JPEG_QUALITY), JPEG_QUALITY])
    if ok:
        with _cam_lock:
            _cam_jpeg = buf.tobytes()


def push_mask(mask):
    """Newest mask frame (single-channel grayscale numpy array)."""
    global _mask_jpeg
    if mask is None:
        return
    ok, buf = cv2.imencode(".jpg", mask, [int(cv2.IMWRITE_JPEG_QUALITY), JPEG_QUALITY])
    if ok:
        with _mask_lock:
            _mask_jpeg = buf.tobytes()


def push_state(**fields):
    """Newest navigation state. Any keyword fields are accepted and forwarded
    to the browser verbatim as JSON."""
    with _state_lock:
        _state.update(fields)
        _state["_ts"] = time.time()


def start(port=8080):
    """Start the HTTP server on a background daemon thread."""
    server = ThreadingHTTPServer(("0.0.0.0", port), _Handler)
    server.daemon_threads = True
    t = threading.Thread(target=server.serve_forever, daemon=True)
    t.start()
    print(f"[dashboard] interface running at http://<this-pi-ip>:{port}/")
    return server
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

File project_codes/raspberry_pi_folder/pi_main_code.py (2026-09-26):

import cv2
import numpy as np
import struct
import serial
import time
import socket
import threading
import heapq
import os
import queue
from picamera2 import Picamera2
import dashboard

# ==========================================================================
# GRAPH-BASED NAVIGATION  (replaces ROUTE_VARIANTS / REROUTE_TAILS)
# --------------------------------------------------------------------------
# The car no longer uses fixed action lists. It localizes on a graph map:
#   - you give it a start node + heading + destination at startup
#   - Dijkstra computes the shortest path that avoids blocked edges
#   - each graph step is converted to a relative action based on heading
#   - YOLO / keyboard closed-road signs block edges and trigger replanning
#
# The low-level motion is unchanged: it still follows colored lines with
# OpenCV/PID, detects junctions, and sends vx/vy/wz/target_yaw/mode to STM32.
#
# Junction camera types (used ONLY to know "a node was reached"):
#   "BOTH"       -> no_line  (both branches open)
#   "LEFT_ONLY"  -> only_right
#   "RIGHT_ONLY" -> only_left
#
# Actions: "STRAIGHT", "LEFT", "RIGHT", "UTURN", "STOP"
#
# Keyboard one-shot rules (applied at the next junction):
#   l = LEFT forbidden    t = RIGHT forbidden
#   f = FORWARD forbidden n = clear all rules
# YOLO auto rules from PC:
#   SAGKAPALI -> RIGHT forbidden     SOLKAPALI -> LEFT forbidden
#   ILERIKAPALI -> FORWARD forbidden (girisyok / no-entry; reroutes, U-turns if needed)
# ==========================================================================

DIRECTIONS = ["NORTH", "EAST", "SOUTH", "WEST"]

GRAPH = {
    "A": {
        "SOUTH": {"to": "A_EXIT", "cost": 1},
    },
    "A_EXIT": {
        "NORTH": {"to": "A", "cost": 1},
        "WEST":  {"to": "CROSS_CENTER", "cost": 4},
        "SOUTH": {"to": "LOWER_RIGHT", "cost": 2},
    },
    "C": {
        "SOUTH": {"to": "CROSS_CENTER", "cost": 1},
    },
    "CROSS_CENTER": {
        "NORTH": {"to": "C", "cost": 1},
        "EAST":  {"to": "A_EXIT", "cost": 4},
        "WEST":  {"to": "LEFT_ROAD", "cost": 4},
        "SOUTH": {"to": "LOWER_CENTER", "cost": 2},
    },
    "LEFT_ROAD": {
        "EAST":  {"to": "CROSS_CENTER", "cost": 4},
        "SOUTH": {"to": "B_EXIT", "cost": 2},
    },
    "B": {
        "NORTH": {"to": "B_EXIT", "cost": 1},
    },
    "B_EXIT": {
        "NORTH": {"to": "LEFT_ROAD", "cost": 2},
        "EAST":  {"to": "LOWER_CENTER", "cost": 4},
        "SOUTH": {"to": "B", "cost": 1},
    },
    "LOWER_CENTER": {
        "NORTH": {"to": "CROSS_CENTER", "cost": 2},
        "WEST":  {"to": "B_EXIT", "cost": 4},
        "EAST":  {"to": "LOWER_RIGHT", "cost": 4},
    },
    "LOWER_RIGHT": {
        "NORTH": {"to": "A_EXIT", "cost": 2},
        "WEST":  {"to": "LOWER_CENTER", "cost": 4},
    },
}

# ----- live navigation state (replaces the old route_* globals) -----
current_node = None            # node the car is currently at / has just reached
current_heading = None         # direction the car is travelling on the current edge
destination = None             # target node
planned_path = None            # list of nodes from current_node to destination
blocked_edges = set()          # set of (node, direction) that must not be used
pending_next_node = None       # node the in-progress movement leads to
pending_target_direction = None  # heading the car will have once the movement finishes
previous_node = None           # node we came FROM (used for NO-PATH U-turn recovery)
no_path = False                # True when Dijkstra cannot reach the destination
forbidden_rules = set()        # active one-shot rules: "LEFT" / "RIGHT" / "FORWARD"
forced_turn_rule = None       # active one-shot YOLO turn rule: "LEFT" / "RIGHT"

# remembered startup values so a reset can restart without re-typing them
init_node = None
init_heading = None
init_dest = None

PORT = "/dev/serial0"
BAUD = 115200
CMD_FMT = "<HhhhfBB"
CMD_HDR = 0xAA55
MODE_ROTATE_YAW = 1
MODE_DRIVE_HEADING = 2

FORWARD_SPEED = 3000
WZ_MAX = 2500

CAM_W = 640
CAM_H = 480
ROI_TOP = 0
ROI_BOTTOM = CAM_H

BANDS_Y = [int(CAM_H * 0.45),   # dotY1
           int(CAM_H * 0.60),   # dotY2 -> ONE LINE / TURN
           int(CAM_H * 0.75)]   # dotX  -> TWO LINE / FOLLOW
BAND_HALF = 12
ROAD_HALF_WIDTH = 160
ONE_LINE_SCAN_HALF_H = 60

MIN_ONE_LINE_AREA = 900
MIN_ONE_LINE_LEN = 60

lower_red1 = np.array([0, 88, 10]);    upper_red1 = np.array([10, 255, 255])
lower_red2 = np.array([160, 88, 10]);  upper_red2 = np.array([180, 255, 255])
lower_pink = np.array([140, 40, 100]); upper_pink = np.array([170, 255, 255])
lower_blue = np.array([100, 50, 50]);  upper_blue = np.array([130, 255, 255])
lower_green = np.array([78, 180, 0]);  upper_green = np.array([94, 255, 255])

clahe = cv2.createCLAHE(clipLimit=2.0, tileGridSize=(8, 8))

KP = 4.0
KI = 0.0
KD = 0.7
pid_integral = 0.0
pid_last_err = 0.0
pid_last_time = time.time()

KP_X = 8.0
CENTER_TOL = 10
MIN_STRAFE = 3500
MAX_STRAFE = 5500
ERROR_ALPHA = 0.65
smooth_error = 0.0
last_road_center = CAM_W // 2

STATE_FOLLOW = 0
STATE_FORWARD_GAP = 1
STATE_TURN = 2
STATE_AFTER_TURN_SIDE = 3
STATE_STRAIGHT_PASS = 4
STATE_DONE = 5
STATE_NO_PATH = 6          # NEW: no route to destination -> stop
STATE_UTURN_BACK = 7       # NEW: after a 180 U-turn, drive back along the road briefly

state = STATE_FOLLOW
state_start = time.time()

ONE_LINE_LIMIT = 40
one_line_counter = 0
NO_LINE_LIMIT = 30
no_line_counter = 0
STOP_CONFIRM_LIMIT = 12

FORWARD_GAP_TIME = 1.85
ONE_LINE_GAP_TIME = 1.60
forward_gap_time = FORWARD_GAP_TIME
STRAIGHT_PASS_TIME = 1.80
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

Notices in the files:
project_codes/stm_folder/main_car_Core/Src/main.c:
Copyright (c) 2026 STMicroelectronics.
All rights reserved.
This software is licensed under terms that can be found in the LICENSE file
